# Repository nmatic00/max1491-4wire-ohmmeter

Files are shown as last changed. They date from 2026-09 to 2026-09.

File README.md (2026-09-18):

# Low-Resistance Meter (2–200 Ω)

This is my first project.

Portable digital ohmmeter designed for accurate low-resistance measurements. This project covers the full electronic system design, including schematic, pcb, enclosure and documentation.

Developed as a coursework project for **Design of Industrial Devices and Measurement Systems 1**.
---

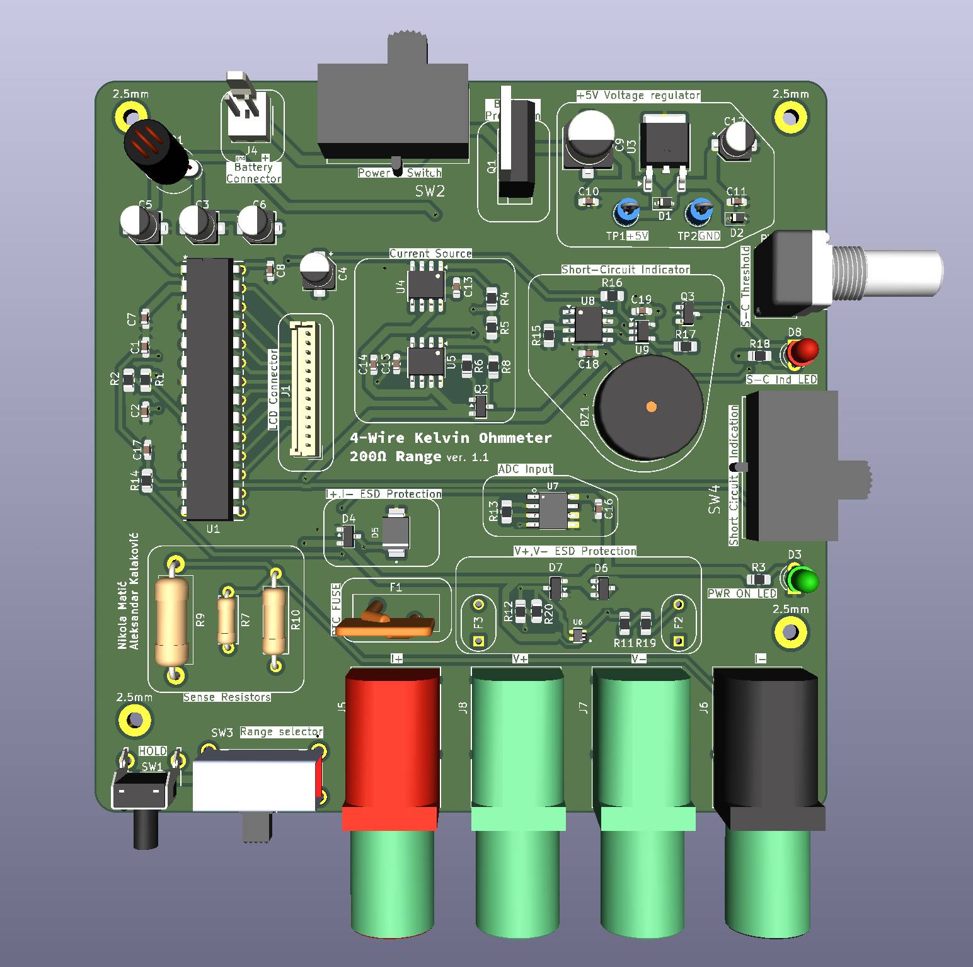
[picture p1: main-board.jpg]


---

## Technical Specifications

| Parameter | Specification |
| :--- | :--- |
| **Measurement Range** | 2 Ω, 20 Ω, and 200 Ω full-scale |
| **Current Source** | 1 mA, 10 mA, and 100 mA (switch-selectable) |
| **Display** | $3\frac{1}{2}$-digit multiplexed LCD (VIM-503-DP-RC-S-HV via MAX1491) |
| **Power Supply** | Single 9 V battery (BT1) with internal +5 V regulation (LM78M05) |
| **Measurement Method** | 4-wire (Kelvin) sensing |
| **Form Factor** | 2-layer $100 \times 100\text{ mm}$ SMD PCB |

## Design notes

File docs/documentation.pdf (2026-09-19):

## PROJECT DOCUMENTATION

# DIGITAL OHMMETER WITH 200 Ω MAXIMUM RANGE

Students: Nikola Matić (EM13/2019), Aleksandar Kalaković (EM23/2019)

Mentor: dr.Marjan Urekar

Design of Industrial Devices and Measurement Systems 1

17.5.2026

1

## Table of Contents

2

## 1 Motivation

The assignment for the course "Design of Industrial Devices and Measurement Systems 1" is to develop a project that demonstrates knowledge and skills in designing the schematic and printed circuit board (PCB) for an electrical device. The project focuses on the development of an instrument for measuring resistance up to 200 Ω. The goal of the project is to acquire and expand knowledge in the field of electronics and low-resistance measurement.

## 2 Introduction

The goal of this project is the development of a measuring instrument capable of measuring resistance in the range of 2 to 200 Ω with practical application in an industrial environment or laboratory.This documentation comprehensively covers the instrument's design, operational principles, and the selection of components integrated into the device itself. The approaches to challenges encountered during development will also be explained sequentially according to the stages of development.

IC | Consumption
MAX1491 | 980 µA
VIM 503-DP-RC-S-HV | 10 µA
LM78M05_TO252 | 10 mA
3x OPA197IDGKT | 3x 1 mA
INA826 | 200 µA
MAX9031AU | 55 µA
Power LED | 15 mA
Ind. k.s. LED | 15 mA
AI-1223-TWT-5V-5-R | 30 mA
Total: | 72.245 mA

Table 1: Consumption estimation Note: The specified values apply to T = 25°C.

3

## 3 Schematic

### 3.1 Power supply

The device is designed to be powered by a single 9 V battery (BT1) that supplies the device with +9 V. The battery is located on a separate board with dedicated access on the enclosure for easier replacement. The battery board connects to the main board of the device via a two-pin power connector (J3 and J4).

On the main board, after the connector, there is a power switch. The switch (SW2) is an SPST (single pole single throw) type, which meets the device's requirements given that it uses a unipolar power supply. The switch allows the user to turn the device on or off without the need to physically disconnect the battery.

The device features reverse polarity protection using a PMOS transistor (Q1) to protect the device in the event of an incorrectly connected battery, connector, etc. Under reverse battery polarity, the PMOS will not conduct, thereby preventing potential damage to the other components of the device. We use the PMOS FQP27P06 because it has a low Rds(on), thereby creating a negligible voltage drop—much lower than if we had used a diode. The Vgs is also critical for us, which for this transistor is ±25 V, enabling reliable protection against a reverse-polarized 9 V battery.

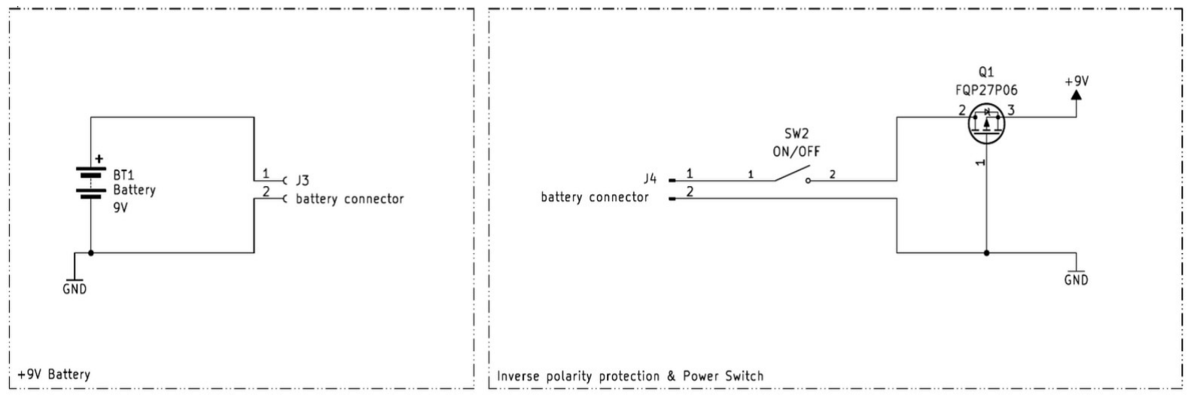
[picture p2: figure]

Figure 1: Battery & Inverse polarity protection

4

Further, the +9 V voltage is fed to the +5 V regulator (U3). This +5 V voltage is used to power all circuits in the device. For the +5 V regulator, we use the LM78M05. This regulator is key to providing a stable voltage for all device components. The regulator was chosen according to the power supply needs (+5 V) and the total current the device can draw. The LM78M05 can provide up to 500 mA of current, which satisfies the needs of this device and leaves headroom for safety. Diodes (D1 and D2) serve to protect the regulator itself from reverse current flow.

Capacitors (C9, C10, C11, C12) serve to further stabilize the voltage and reduce the impact of environmental noise. Two electrolytic capacitors (C9, C12) and two ceramic block capacitors (C10, C11) are used.
At the output of the regulator, there is an indicator LED (D3) that serves to indicate the state of the device. Test points (TP1 and TP2) allow easy access to the supply voltage for easier diagnostics.

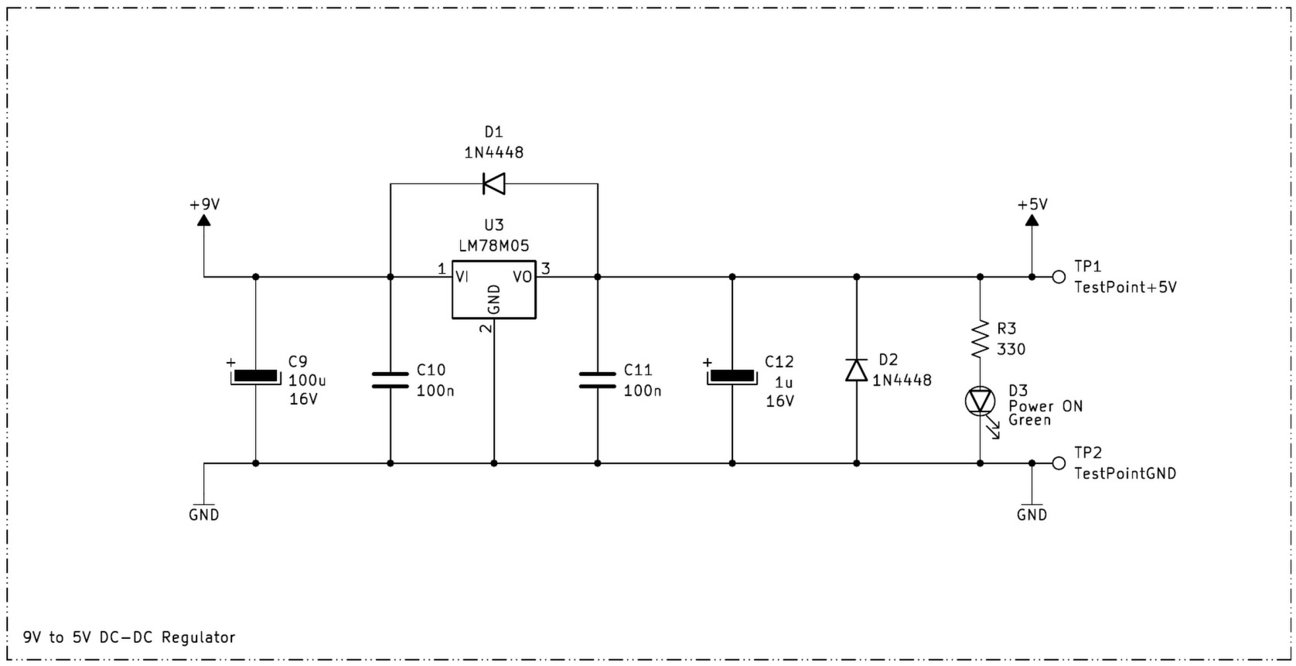
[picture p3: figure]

Figure 2: 9 V to 5 V DC-DC regulator

5

### 3.2 Current source

To design the ohmmeter, a constant current source is required. In order to determine the value of the resistance being measured, we must pass a known current through that resistance and then measure the voltage drop across it. The constant current source consists of two operational amplifiers (U4 and U5), a PMOS transistor (Q2), and sense resistors (R7, R9, R10). This current source is designed to precisely provide the current value required for a given measurement. It is adjustable across ranges of 1 mA, 10 mA, and 100 mA, which correspond to the measurement ranges of this device (200 Ω, 20 Ω, and 2 Ω, respectively). Range selection is implemented using a DP3T switch (SW3), which selects the current range while simultaneously sending a signal to the main chip regarding the selected range—i.e., the position of the decimal point.

The current source features overvoltage protection and electrostatic discharge (ESD) protection, as well as a PTC fuse that protects against overcurrent. Overvoltage protection is realized using a pair of BAT54S diodes (D4) that clamp the voltage within the operating voltage range. ESD protection is implemented via an SMBJ5.0A TVS diode (D5), which protects the remaining components in the event of a surge. In the case of a fault current, a resettable PTC fuse (F1) with a hold current of up to 200 mA trips to isolate the circuit. The output of this current source is provided via S16N-PC jacks (J5 and J6), which serve as the device's current terminals.

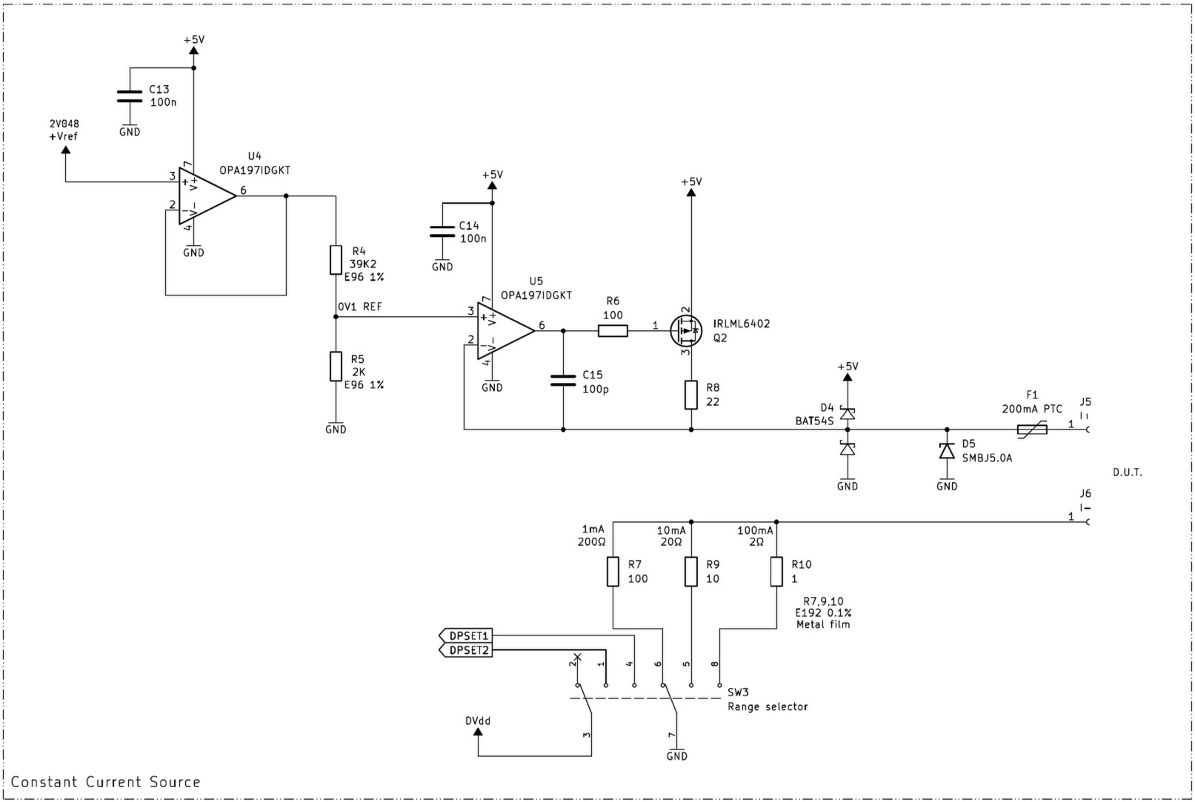
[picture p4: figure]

Figure 3: Constant Current Source

6

### 3.3 Input element

The input stage of the device consists of two S16N-PC jacks, input protection, an INA826 instrumentation amplifier, and an RC filter. The jacks (J7 and J8) serve as the voltage sense terminals of the device and are connected to the ADC inputs via the INA826 instrumentation amplifier (U7).

Input protection is implemented through a pair of PTC fuses (F2 and F3), a two-channel bidirectional TVS diode TP2E001DRLRG4 (U6) that protects the inputs from ESD, and two pairs of BAT54S diodes (D6 and D7) that provide overvoltage protection. The inputs of the instrumentation amplifier (U7) are protected against overcurrent by resistors (R11, R19 and R12, R20) in a manner that does not significantly affect measurement accuracy due to the low input bias current of the INA826 (U7). The instrumentation amplifier (U7) is configured to amplify the voltage signal with a range up to 200 mV to 2 V, for which the ADC is calibrated.

The RC filter formed by the combination of a resistor (R14) and a capacitor (C17) serves to eliminate external noise that could affect the measured signal. This is achieved by attenuating high frequencies typical of external interference.

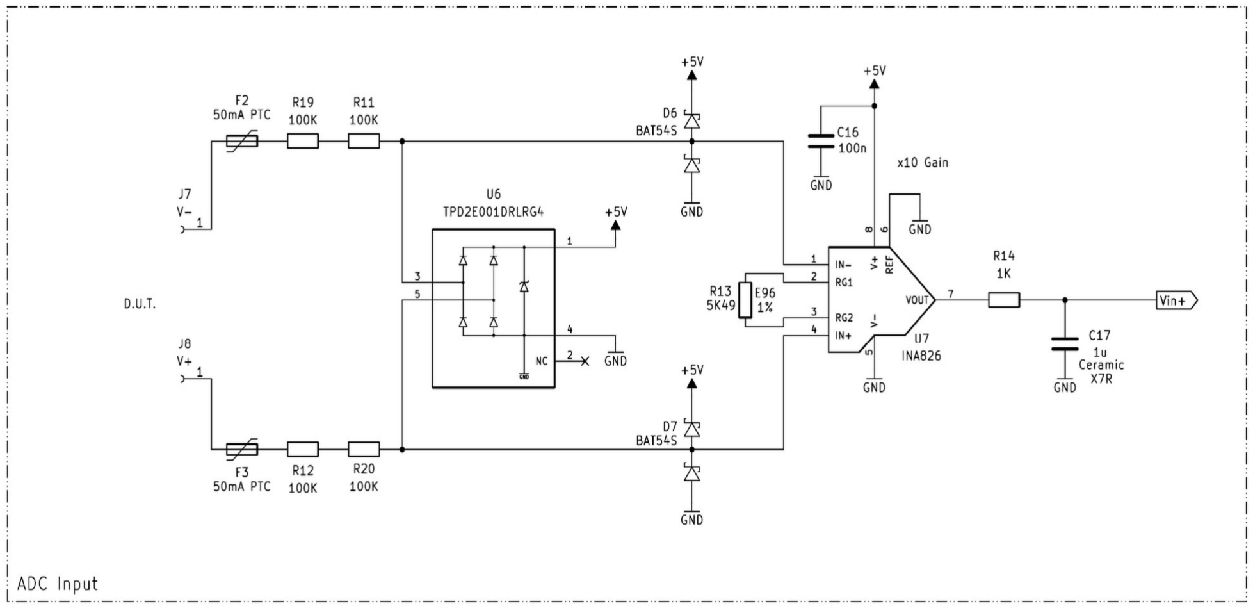
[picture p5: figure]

Figure 4: Input element

7

### 3.4 Continuity tester

The continuity tester is useful when diagnosing circuits. The indicator threshold is adjustable from 1 to 50 Ω and features both audio and visual indication.

A MAX9031 comparator (U9) is used to detect a "short circuit" using an adjustable reference voltage. This comparator features an integrated 4 mV hysteresis, which prevents output oscillation near the comparison threshold.

The reference voltage is implemented via a voltage divider consisting of a resistor (R16) and a potentiometer (RV1). The voltage divider is configured for a range corresponding to 1 to 50 Ω. By adjusting the potentiometer, the user can tune the comparator's voltage threshold.

Audio indication is provided by an active buzzer (BZ1) that emits a high-frequency tone upon detecting a "short circuit". Visual indication is provided by a red LED (D8).

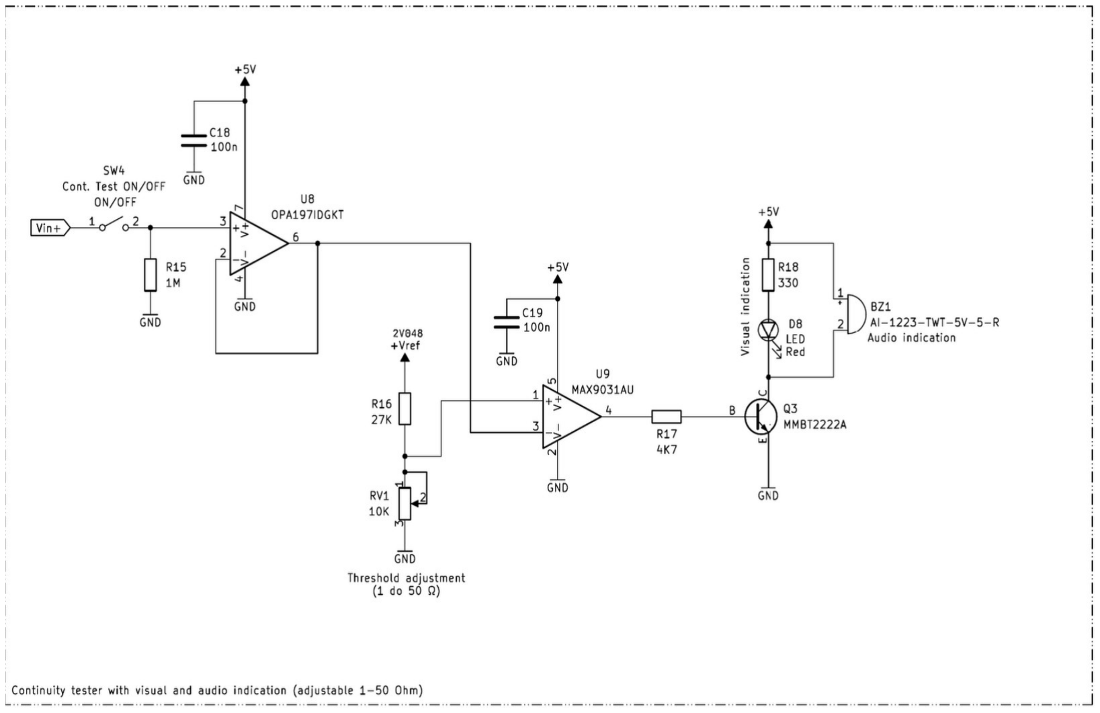
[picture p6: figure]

Figure 5: Continuity Tester

8

### 3.5 ADC circuit

A MAX1491 (U1) is used, which is an ADC with integrated LCD drivers offering 3½-digit resolution. This ADC provides high measurement precision and enables easy display of results on an LCD screen. Its low power consumption makes it suitable for battery-powered measuring devices. It is set to a 2 V range via the RANGE pin (pin 10) connected to ground, which corresponds to the output of the instrumentation amplifier.

A HOLD function is provided via a push button (SW1). This feature allows the user to freeze the displayed measurement result on the LCD screen at the press of a button. Low battery voltage indication is implemented using a voltage divider (R1, R2). When the battery voltage drops below 4.7 V, the LOWBATT segment lights up on the LCD screen.

The LCD outputs of the MAX1491 are multiplexed using triplex logic with a ⅓ duty cycle signal. This approach significantly reduces the number of pins required to interface with the LCD screen. The LCD outputs are connected to the LCD connector (J1).

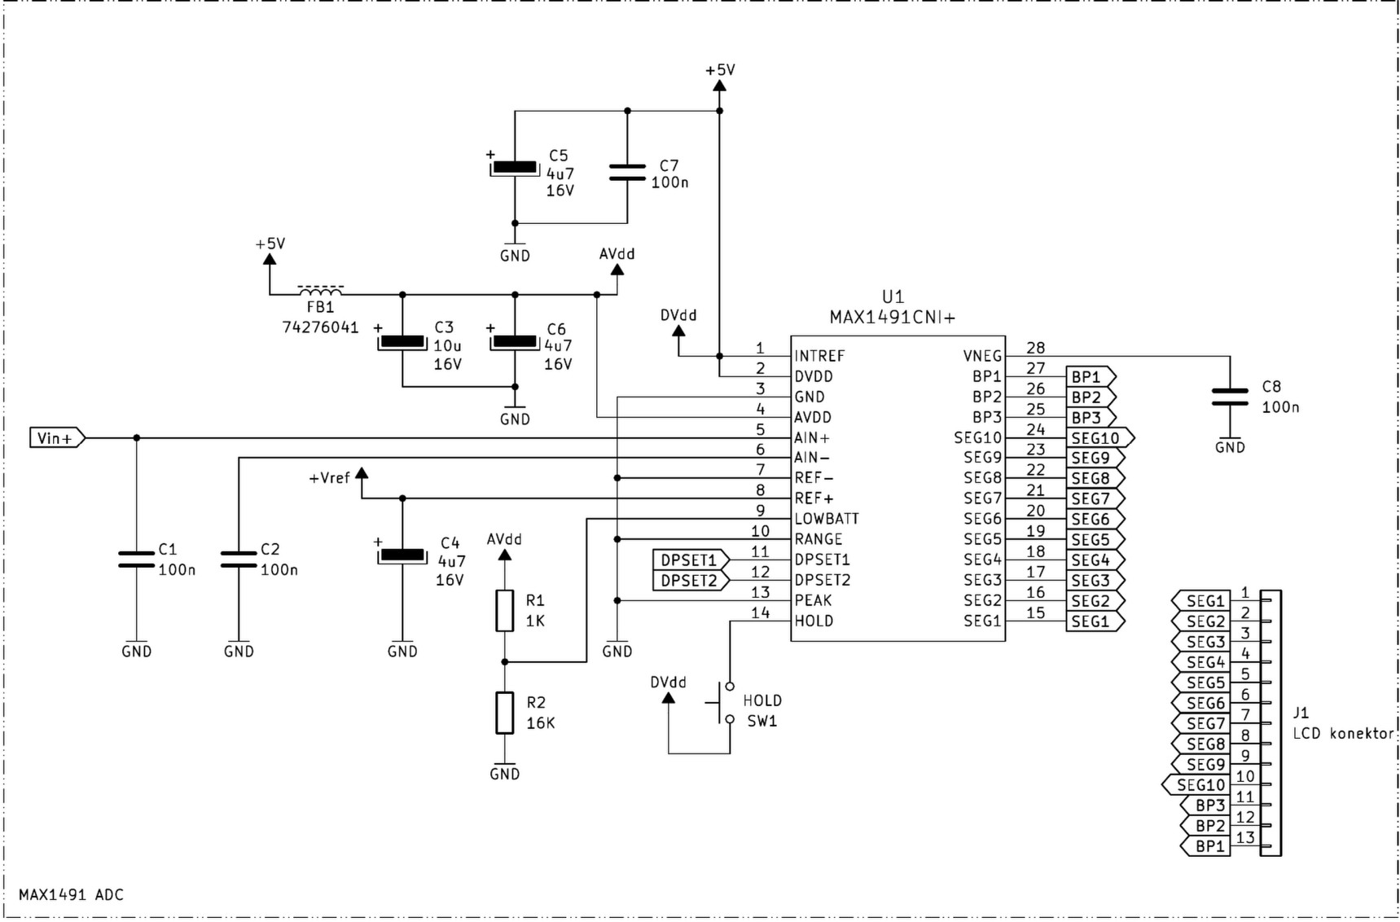
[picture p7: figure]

Figure 6: ADC circuit

9

### 3.6 LCD

The LCD screen (U2) is mounted on a separate PCB for greater flexibility when assembling it into the enclosure. The LCD connects to the MAX1491 via LCD connectors (J1 and J2). The connector used is a Hirose DF13-13P. The LCD used is the VIM-503-DP-RC-S-HV. It is a static TN panel with multiplexed inputs, enabling straightforward interfacing with the MAX1491. The LCD panel itself features a 4½-digit display, of which 3½ digits are used to match the output of the MAX1491. Selecting this LCD represents a trade-off regarding project complexity; while a 3½-digit LCD with the same triplex multiplexing scheme is theoretically possible, it was not off-the-shelf available and would require custom manufacturing. Choosing this display avoids the complexity of adapting a passive display panel to the MAX1491 output logic.

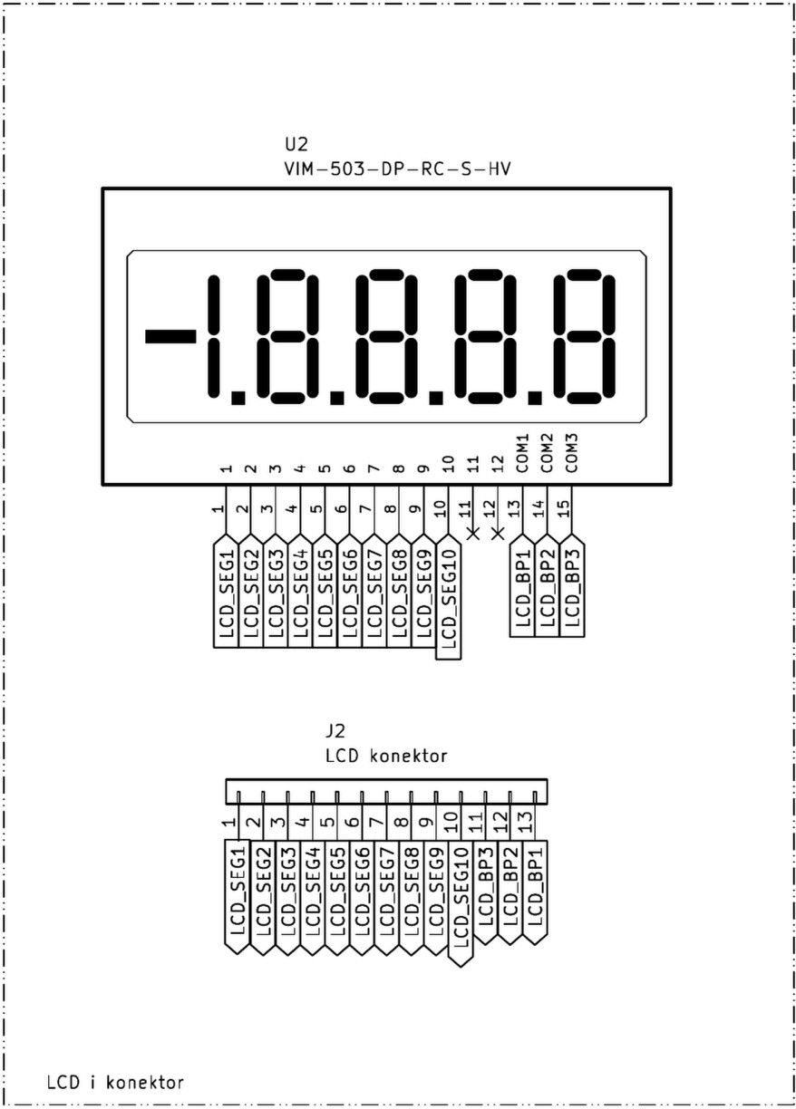
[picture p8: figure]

Figure 7: LCD & Connector

10

## 4 PCB

### 4.1 Main board

The board is constructed with two layers, with components placed on the top layer. Both layers feature a copper pour tied to ground (GND). This simplifies ground routing and minimizes the amount of copper that needs to be etched off during production. It also improves electromagnetic stability, making the device more resistant to noise.

Trace widths on the board were chosen to guarantee proper functionality and ensure physical durability:
- 50 mils (1.270 mm) for power supply traces
- 20 mils (0.508 mm) for signal traces

The aforementioned input protections are located away from other circuitry to prevent potential damage from high temperatures, overcurrent, or arcing. It is critical that these protective components be placed close to the input jacks for rapid fault response (especially PTC fuses F1, F2, and F3).

The voltage sense terminals are positioned between the current terminals with clear spacing to naturally discourage improper connections by the user. Color-coded terminals further reinforce this setup: the I+ terminal is red, while I- is black. The device is designed for use with specialized cables known as Kelvin clamps, which connect to I+ and V+, and I- and V-, respectively.

The device controls are strategically positioned along the edges of the board. The power switch is located on the rear panel, while the input jacks, HOLD button, and range selector are on the front panel. The short-circuit indicator switch and its threshold adjustment potentiometer are positioned on the right side.

All components on the board are grouped by circuit function and clearly labeled on the silkscreen. This significantly simplifies cross-referencing schematic functional blocks with physical board components. The PCB is designed primarily around SMD (Surface Mount Device) components. Compared to THT (Through Hole Technology), SMD components allow for a significantly smaller form factor, enabling the main board to fit within a 100x100 mm footprint. Compact physical dimensions are vital here, as a battery-powered device must remain portable and easy to handle.

11

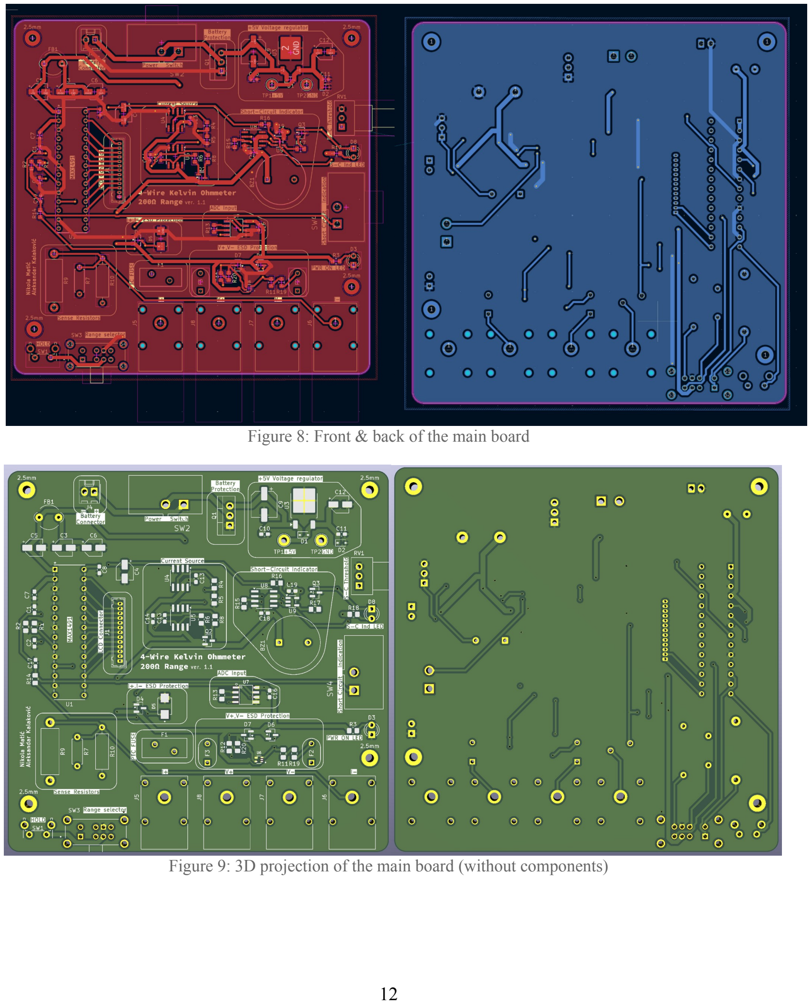
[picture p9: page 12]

Figure 8: Front & back of the main board

Figure 9: 3D projection of the main board (without components)

12

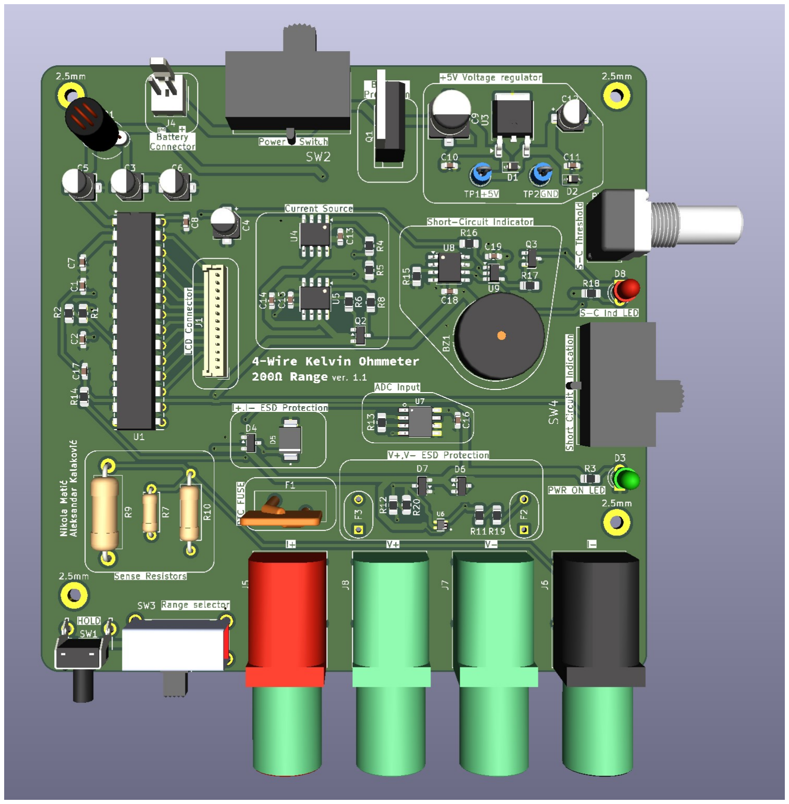
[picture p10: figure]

Figure 10: Main board with components

13

### 4.2 LCD board

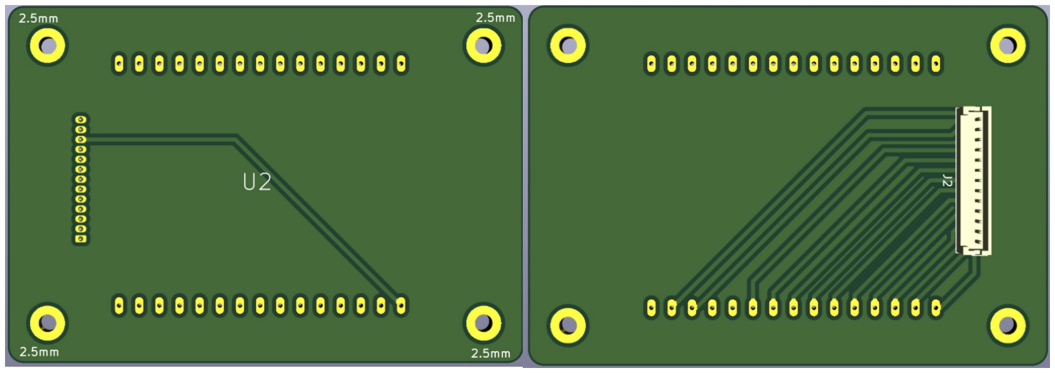
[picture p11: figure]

Figure 11: Front & back of the LCD board

### 4.3 Battery board

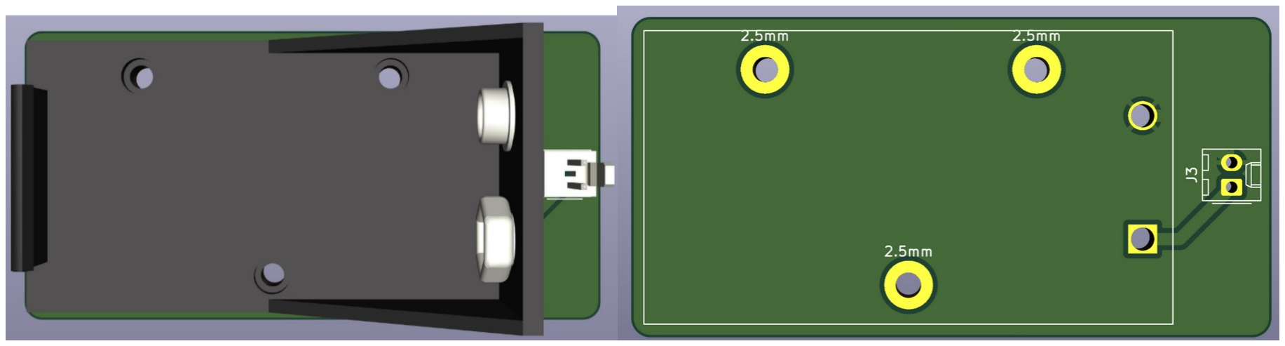
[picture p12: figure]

Figure 12: Front & back of the battery board

14

## 5 Enclosure

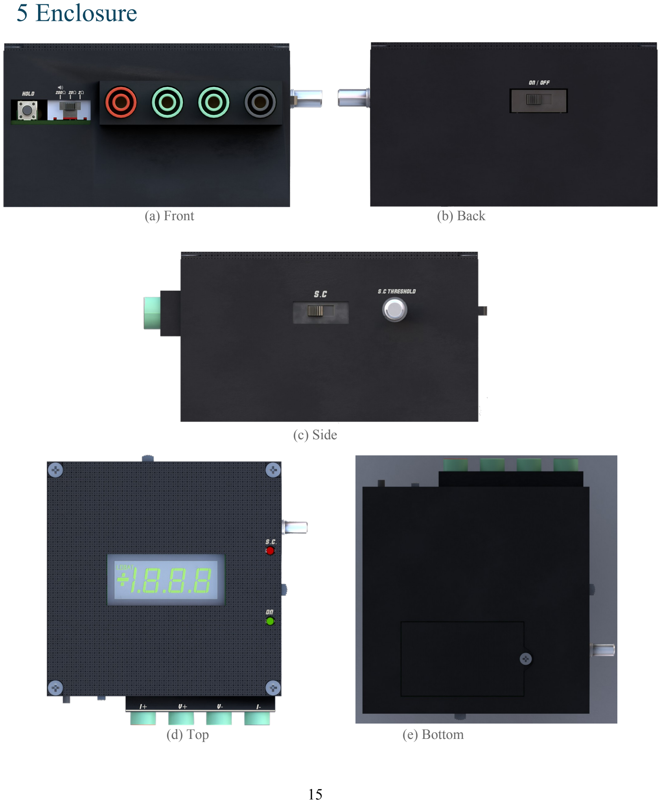
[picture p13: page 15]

(a) Front | (b) Back
(c) Side
(d) Top | (e) Bottom

15

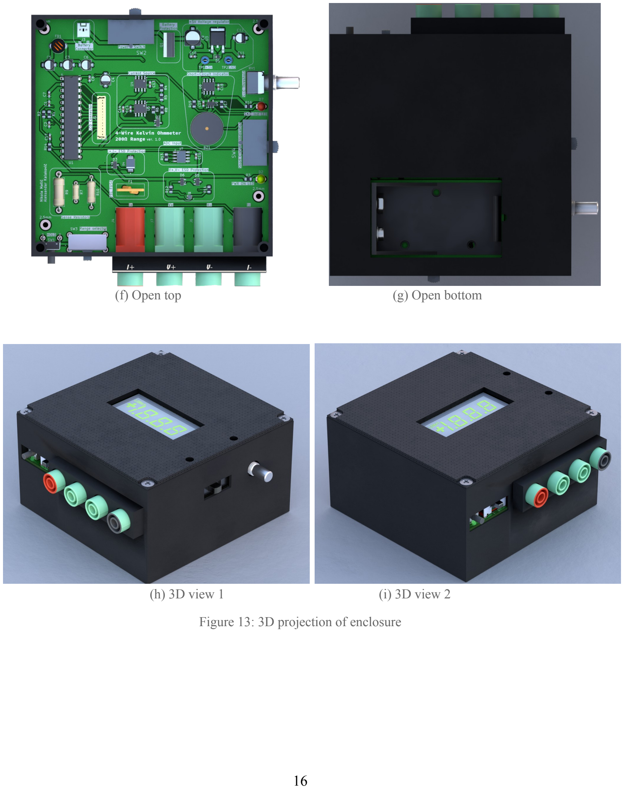
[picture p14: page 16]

(f) Open top | (g) Open bottom
(h) 3D view 1 | (i) 3D view 2

Figure 13: 3D projection of enclosure

16

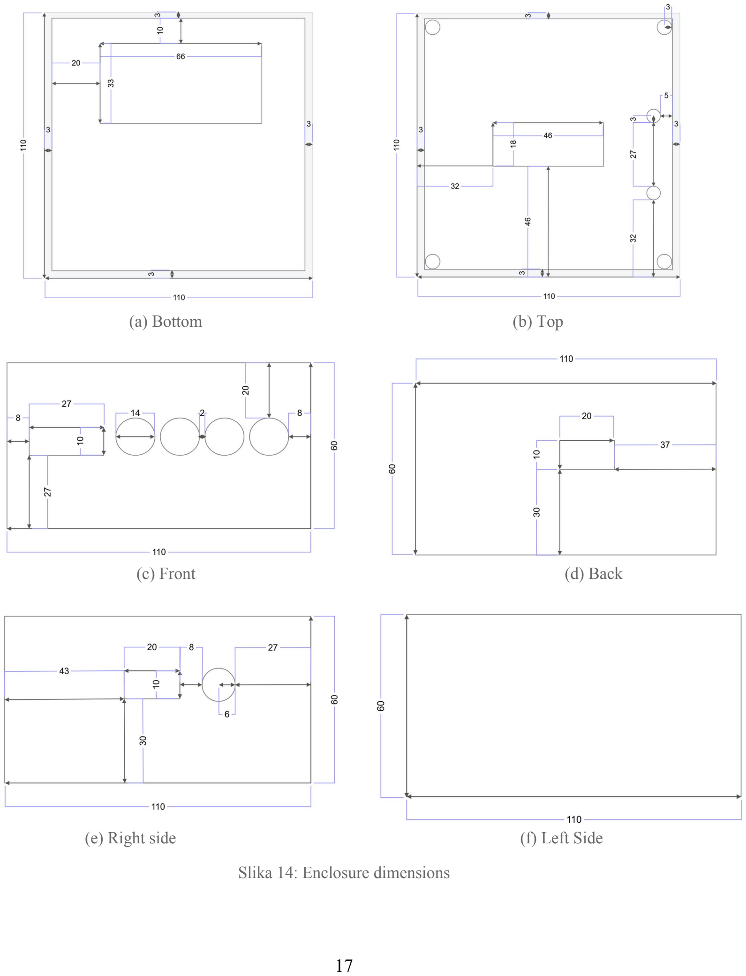
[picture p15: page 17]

(a) Bottom | (b) Top
(c) Front | (d) Back
(e) Right side | (f) Left Side

Slika 14: Enclosure dimensions

17

## 6 BOM

Item | Value | Reference | Footprint | Qty Mfr. part No. | Price (piece)(€)Price (€)
1 | Battery | BT1 | 12BH611-GR | 1 | 12BH611-GR | 1,46 | 1,46
2 | Buzzer | BZ1 | AI-1223-TWT-5V-5-R | 1 | AI-1223-TWT-5V-5-R | 1,35 | 1,35

3 100n

C1, C2, C7, C8,
C10, C11, C13,
C14, C16, C18,
C19 | _0603 | 11 GCM188R71H104KA57D | 0,03 | 0,33
4 | 10u | C3 | 4x5.4 | 1 | EXV106M035A9DAA | 0,43 | 0,43
5 | 4u7 | C4, C5, C6 | 4x5.4 | 3 | EXV475M035A9BAA | 0,37 | 1,11
6 | 100u | C9 | 6.3x5.9 | 1 | MAL214699805E3 | 1,79 | 1,79
7 | 1u | C12 | 4x4.5 | 1 | EDH105M050A9BAA | 0,16 | 0,16
8 | 1u | C17 | _0603 | 1 | 0603X7R105KT7AT | 0,49 | 0,49
9 | 100p | C15 | _0603 | 1 | KGQ15ACG2A101JM | 0,05 | 0,05
10 | 1N4448 | D1 | SOD-323 | 1 | 1N4448WS-HE3_A-08 | 0,55 | 0,55
11 | Power ON | D2 | LED_D3.0mm | 1 | SLX-LX3054HD | 0,04 | 0,04
12 | BAT54S | D3, D5, D6 | SOT-23 | 3 | BAT54S | 0,12 | 0,36
13 | SMBJ5.0A | D4 | DIOM4336X265N | 1 | SMBJ5.0A | 0,53 | 0,53
14 | LED | D7 | LED_D3.0mm | 1 | SLX-LX3054HD | 0,04 | 0,04
15 | PTC Fuse | F1 | MF-RX020/72-0 | 1 | MF-RX020/72-0 | 0,34 | 0,34
16 | Ferrite Bead | FB1 | 28C0236-0JW-10 | 1 | 74276041 | 0,12 | 0,12
17 | LCD konektor | J1, J2 | Hirose_DF13-13P-1.25DSA 2 | DF13-13P-1.25DSA(55) | 1,01 | 2,02
18 | Konektor baterije | J3, J4 | KK-254_AE-6410-02A | 2 | 22272021 | 0,18 | 0,36
19 | I+,I-,V+,V- | J5, J6, J7, J8 | FCR7350R_S16N-PC | 4 | FCR7350R_S16N-PC | 4,9 | 19,6
20 | FQP27P06 | Q1 | TO-220-3 | 1 | FQP27P06 | 2,51 | 2,51
21 | IRLML6402 | Q2 | SOT-23 | 1 | IRLML6402TRPBF | 0,39 | 0,39
22 | MMBT2222A | Q3 | SOT-23 | 1 | MMBT2222A | 0,1 | 0,1
23 | 1K | R1, R14 | _0805 | 2 | RMCF0805JG1K00 | 0 | 0
24 | 16K | R2 | _0805 | 1 | RC0805JR-0716KL | 0,09 | 0,09
25 | 330 | R3, R17 | _0805 | 2 | RK73B2ATTE331J | 0,1 | 0,2
26 | 39K2 | R4 | _0805 | 1 | CRCW201039K2FKEF | 0,3 | 0,3
27 | 2K | R5 | _0805 | 1 | RC0805FR-7W2KL | 0,1 | 0,1

18

28 | 100 | R7 | DIN0207 | 1 | PTF56100R00BYEB | 5,15 | 5,15
29 | 100 | R6 | _0805 | 1 | RK73B2ATTE101J | 0,1 | 0,1
30 | 22 | R8 | _0805 | 1 | SR0805JR-7W22RL | 0,1 | 0,1
31 | 10 | R9 | DIN0414 | 1 | UPF50B10RV | 4,5 | 4,5
32 | 1 | R10 | DIN0309 | 1 | RS1/21R000BB12 | 19,44 | 19,44

33 100K

| | R11, R12,
| | R19,R20 | _0805 | 4 | SG73S2ATTD104G | 0,2 | 0,8
34 | 5K49 | R13 | _0805 | 1 | RT1206FRE075K49L | 0,1 | 0,1
35 | 1M | R15 | _0805 | 1 | TC0550F1004T5G | 0,01 | 0,01
36 | 27K | R16 | _0805 | 1 | AC0805JR-0727KL | 0,09 | 0,09
37 | 4K7 | R18 | _0805 | 1 | CRCW08054K70JNEAIF | 0,29 | 0,29
38 | 10K | RV1 | RK09Y11 | 1 | RK09Y11L0001 | 1,84 | 1,84
39 | HOLD | SW1 | PTS645VM83-2 LFS | 1 | PTS645VM83-2 LFS | 0,34 | 0,34
40 | ON/OFF, Indikacija K.S. | SW2, SW4 | L101011ML04Q | 2 | L101011ML04Q | 2,55 | 5,1
41 | Odabir opsega | SW3 | MHS233RA04 | 1 | MHS233RA04 | 2,62 | 2,62
42 | MAX1491CNI+ | U1 | 21-0043D_28_MXM | 1 | MAX1491CNI+ | 15,24 | 15,24
43 | LM78M05_TO252 | U3 | TO-252-2 | 1 | LM78M05CDTX/NOPB | 1,39 | 1,39
44 | OPA197IDGKT | U4, U5, U8 | SOIC-8 | 3 | OPA197IDGKT | 1,78 | 5,34
45 | TPD2E001DRLRG4 | U6 | SOTFL50P160X60-5N | 1 | TPD2E001DRLRG4 | 0,77 | 0,77
46 | INA826 | U7 | SO-8 | 1 | INA826AID | 3,52 | 3,52
47 | MAX9031AU | U9 | SOT-23-5 | 1 | MAX9031AUK+T | 1,39 | 1,39
48 | VIM-503-DP-RC-S-HV | U2 | VIM-503-DP-RC-S-HV | 1 | VIM-503-DP-RC-S-HV | 5,66 | 5,66
49 | 50mA PTC | F2, F3 | CMF_RL50A-0_BRN | 2 | CMF-RL50A-0 | 0,61 | 1,22
Total: | | | | | | | 109,8

Table 2: BOM (Mouser 20.5.2026.)

19

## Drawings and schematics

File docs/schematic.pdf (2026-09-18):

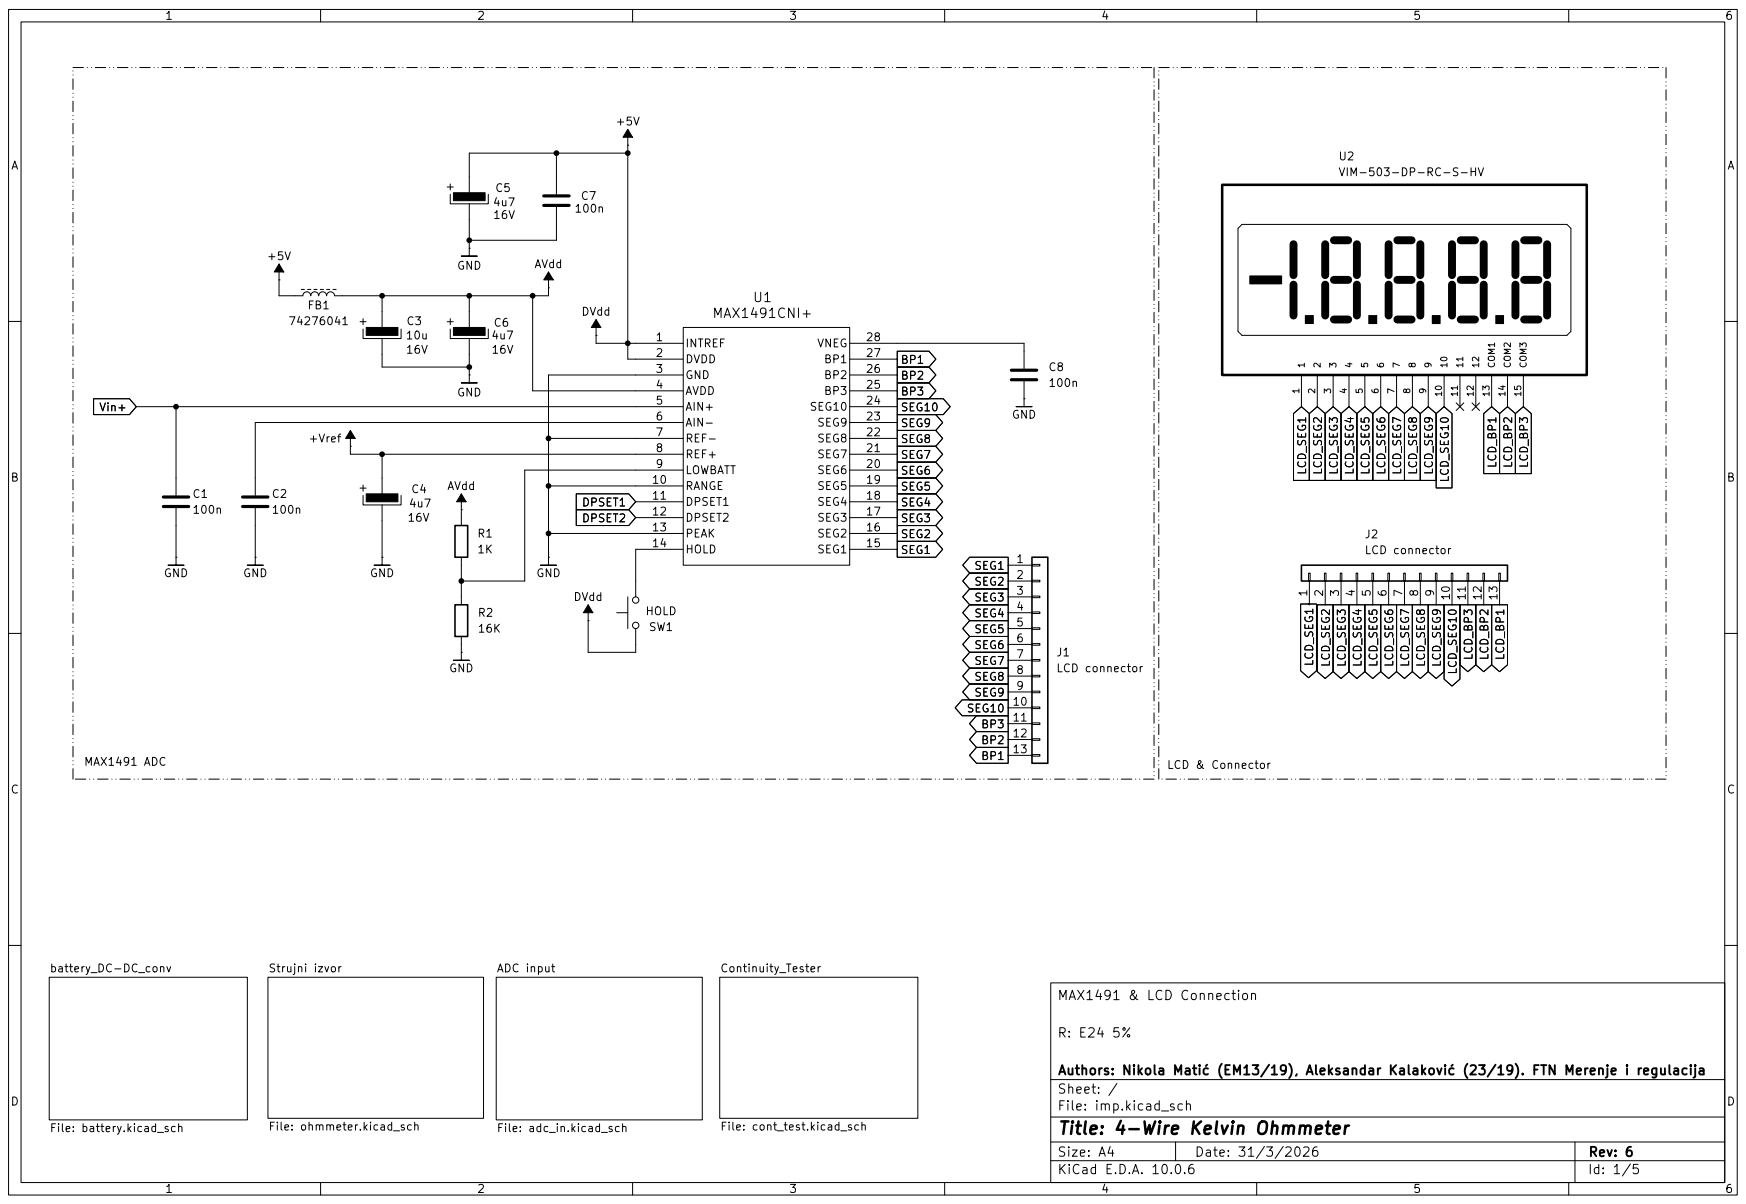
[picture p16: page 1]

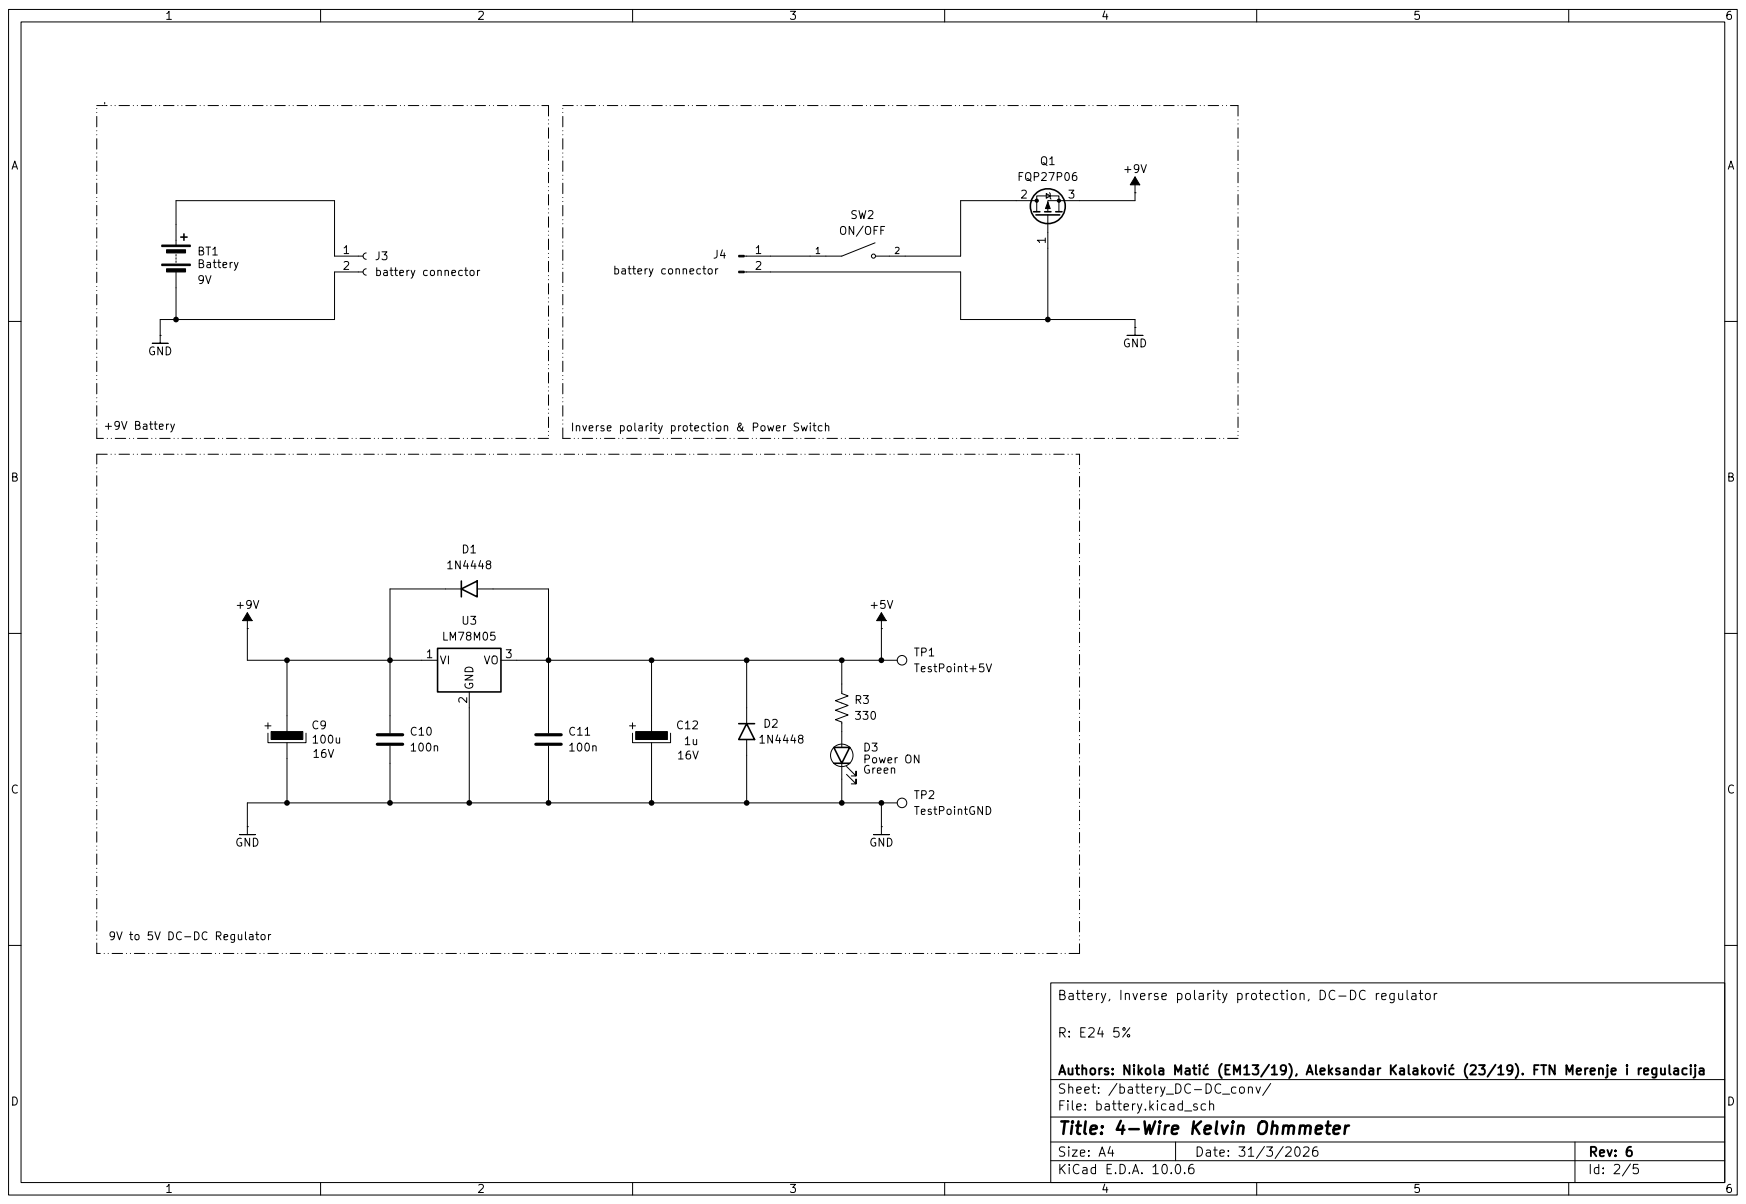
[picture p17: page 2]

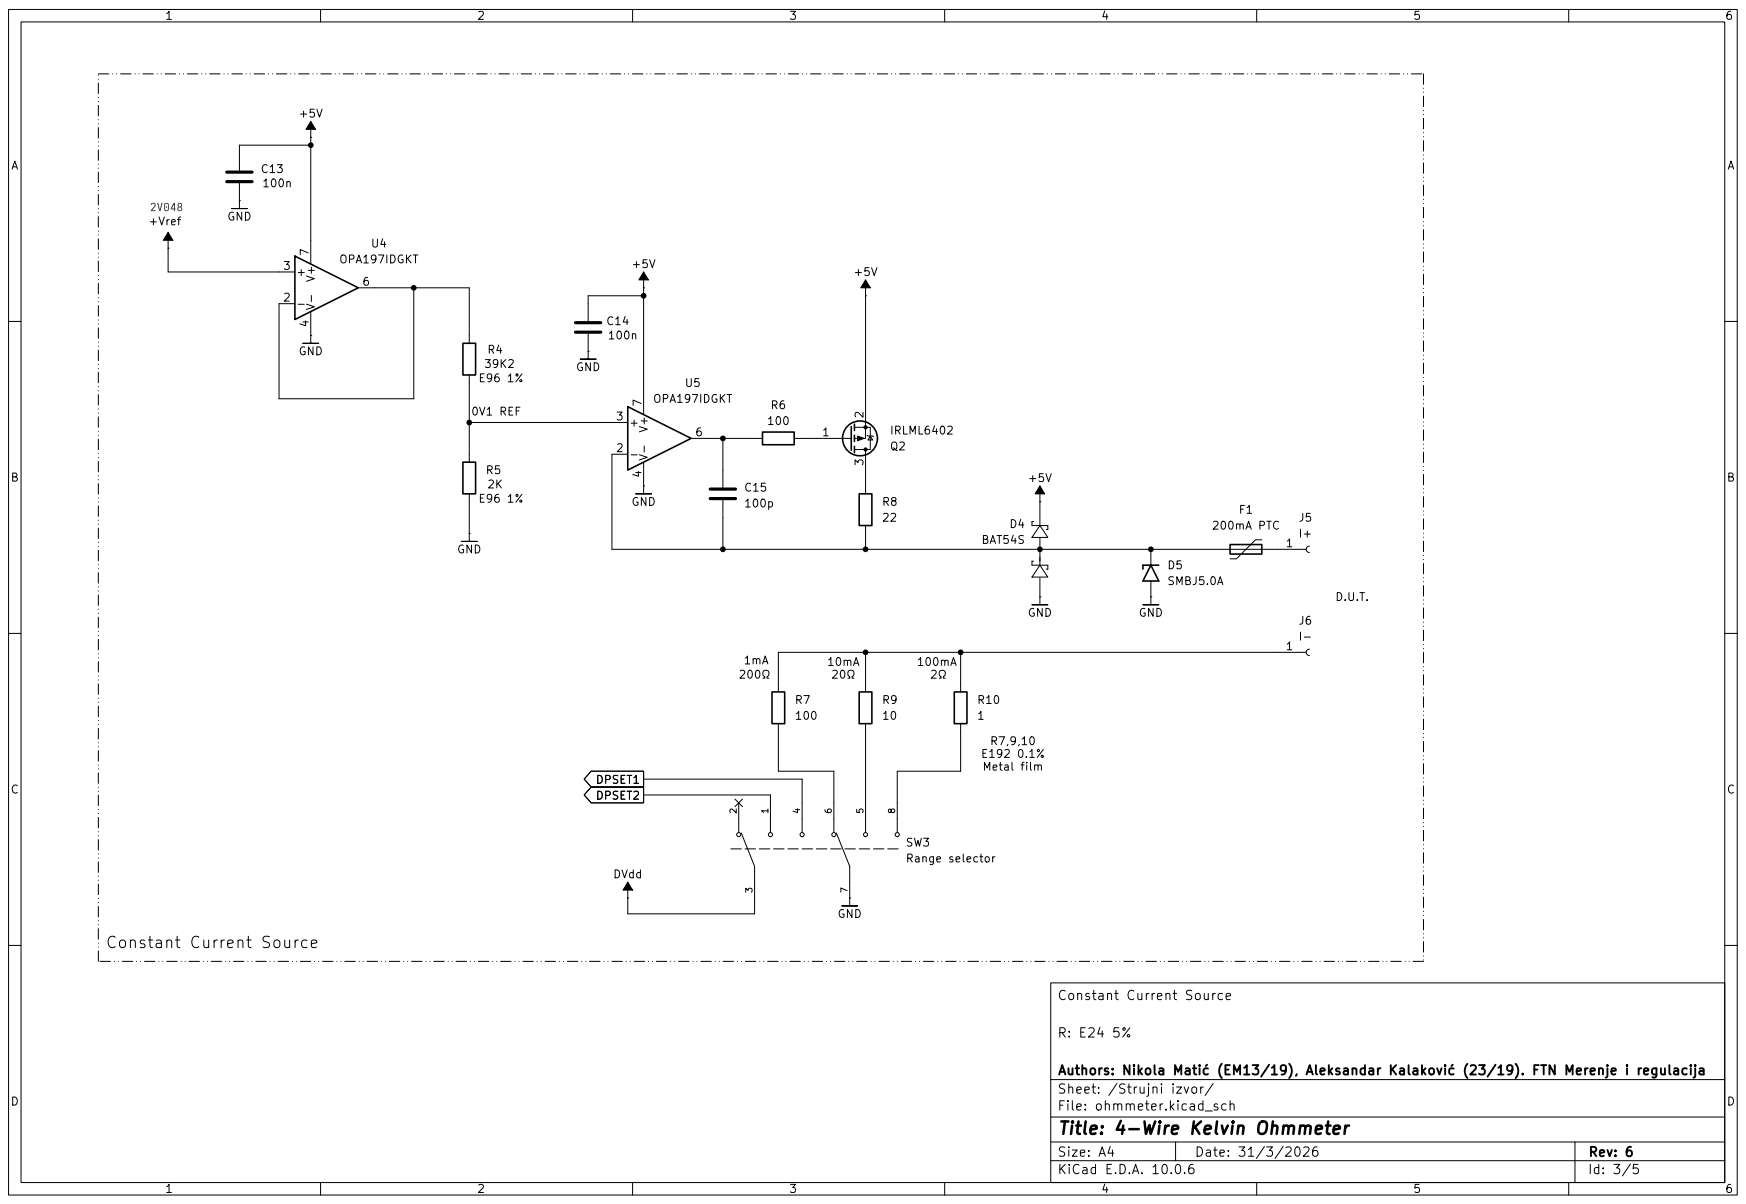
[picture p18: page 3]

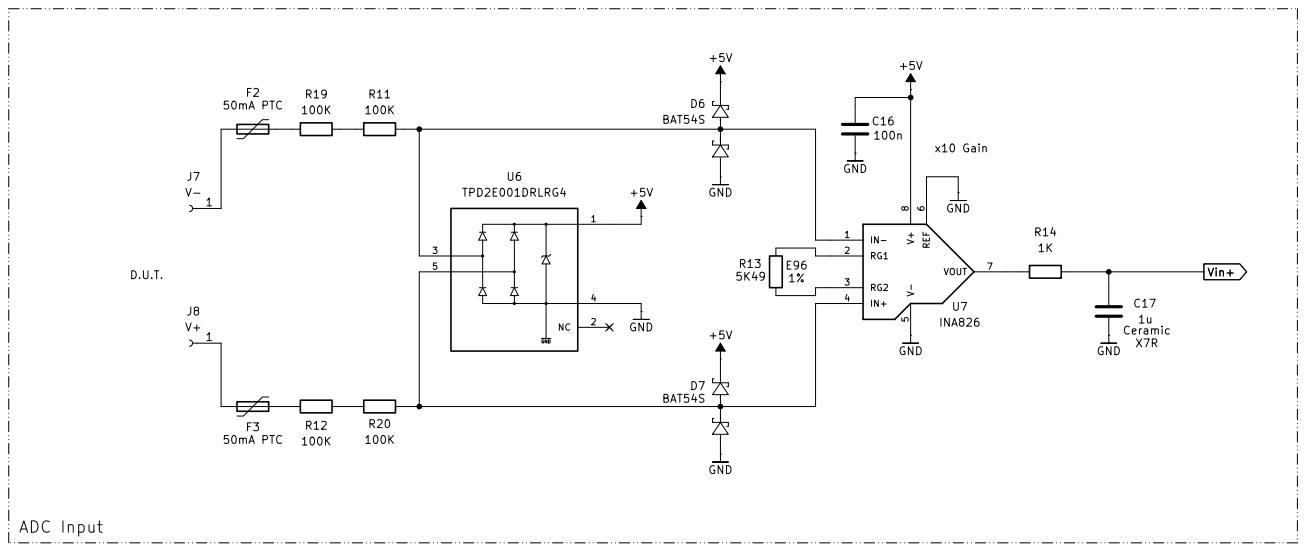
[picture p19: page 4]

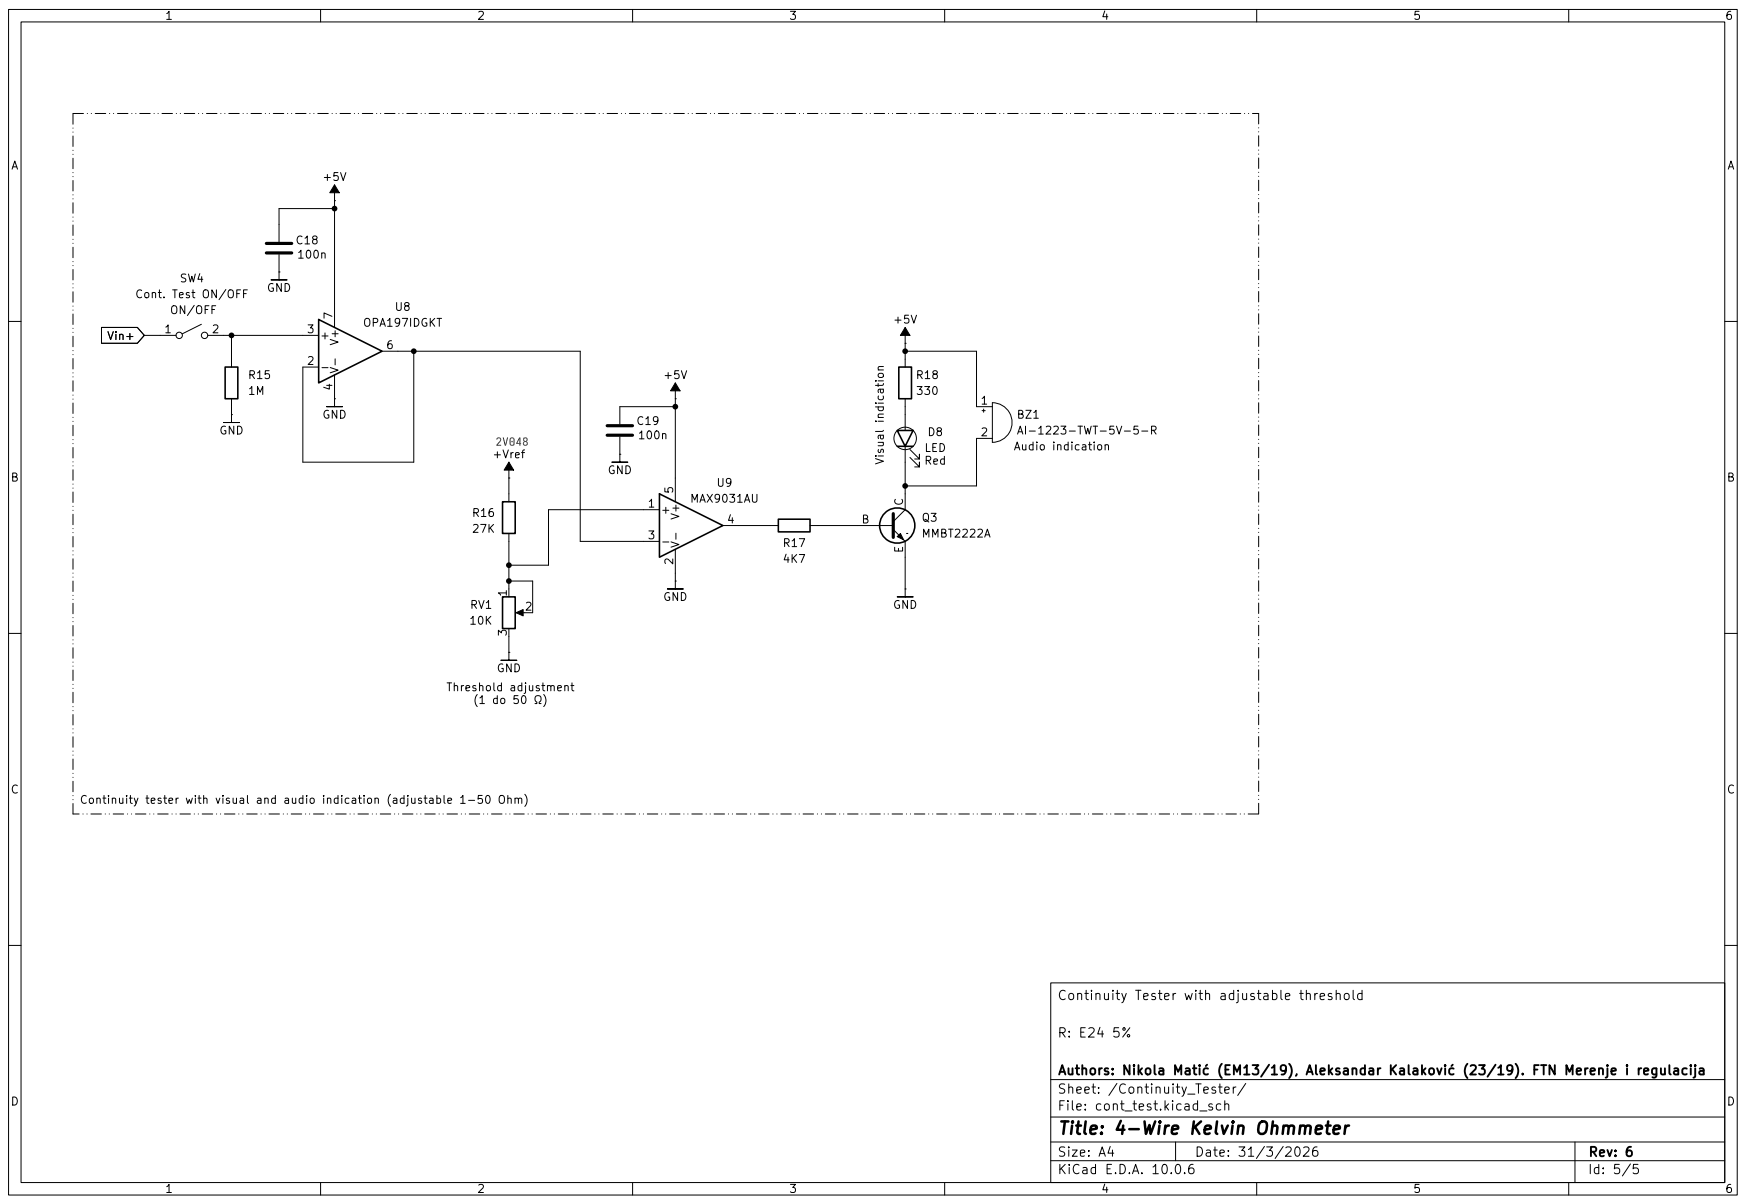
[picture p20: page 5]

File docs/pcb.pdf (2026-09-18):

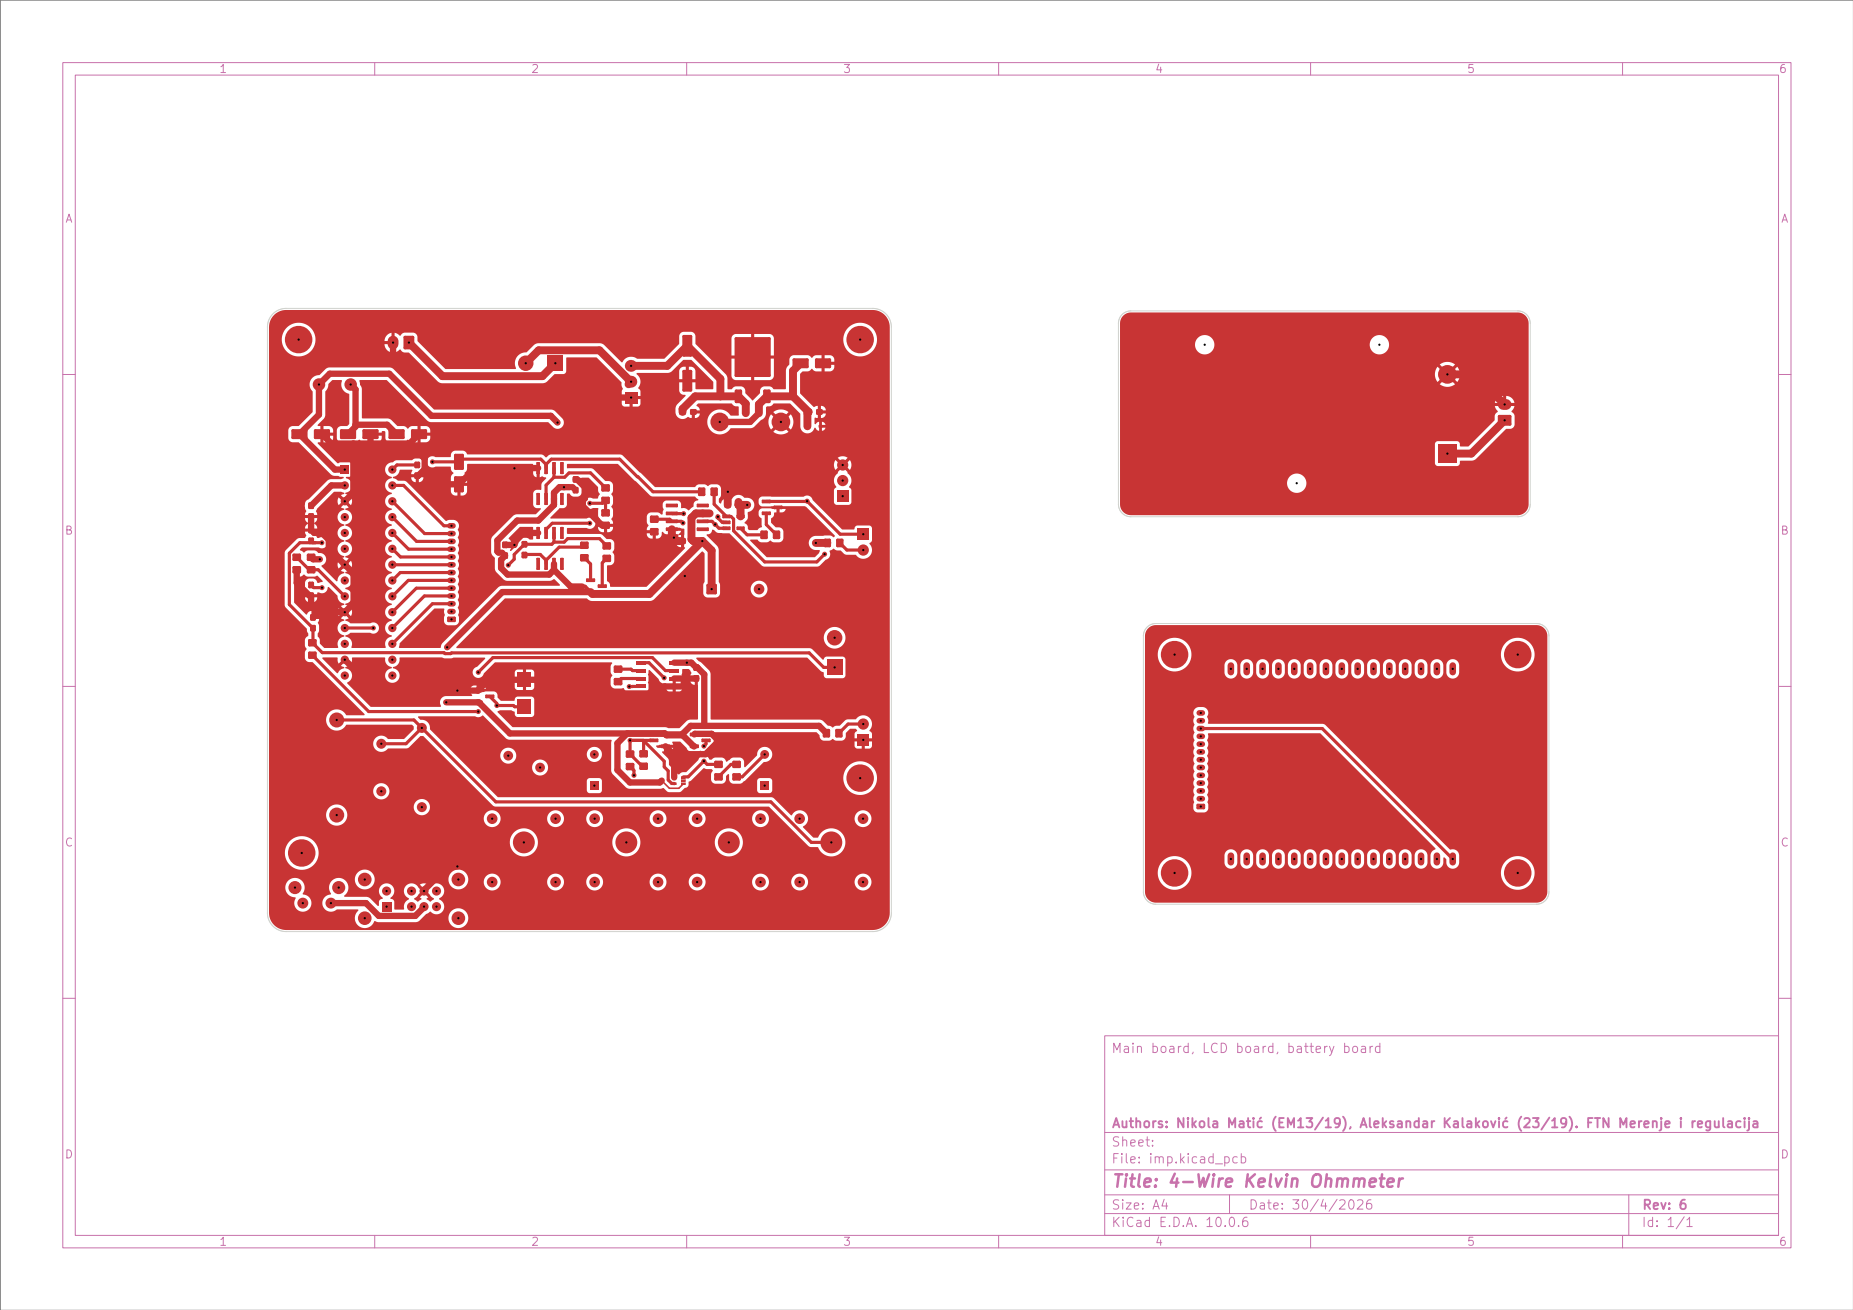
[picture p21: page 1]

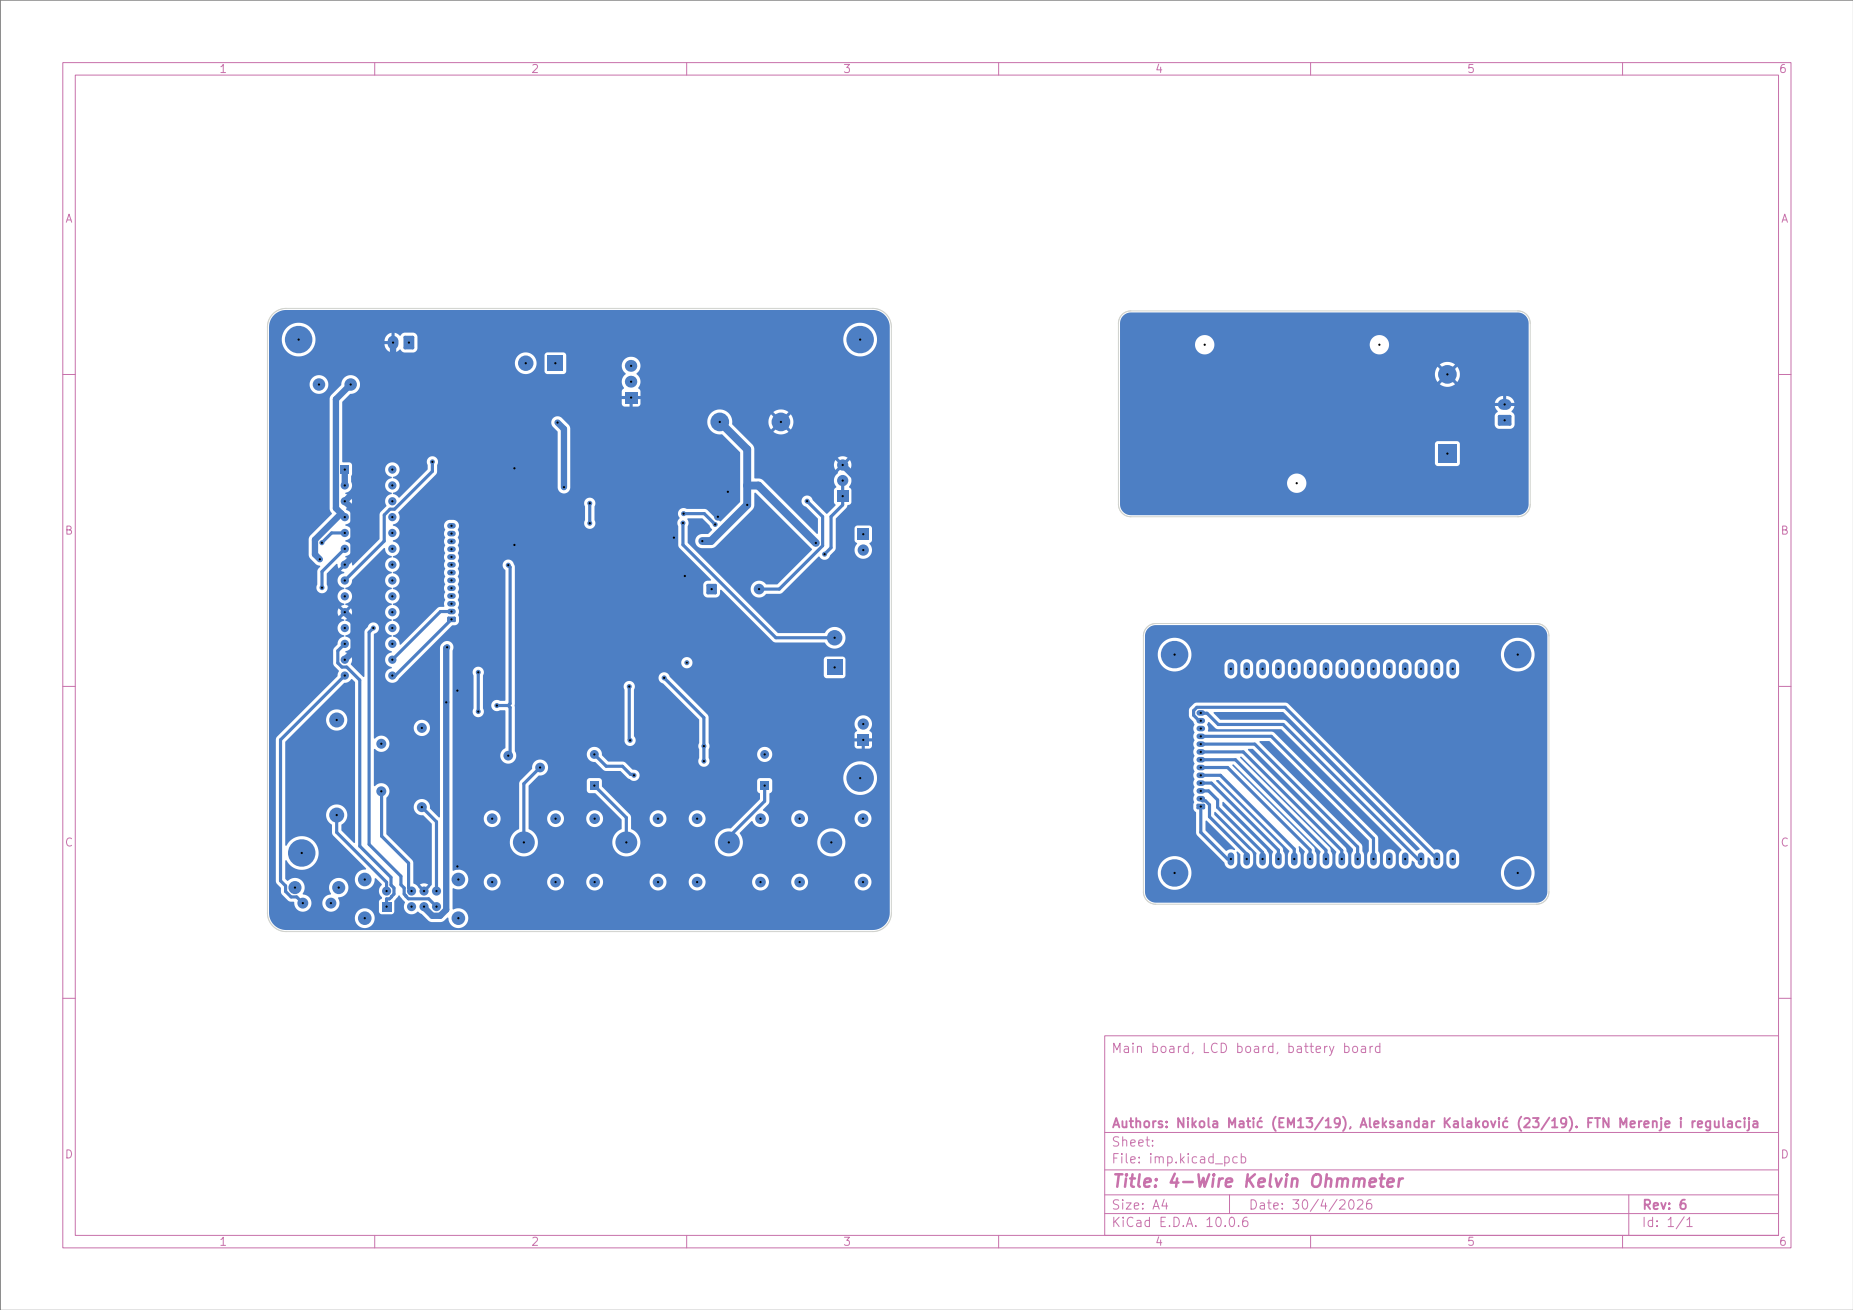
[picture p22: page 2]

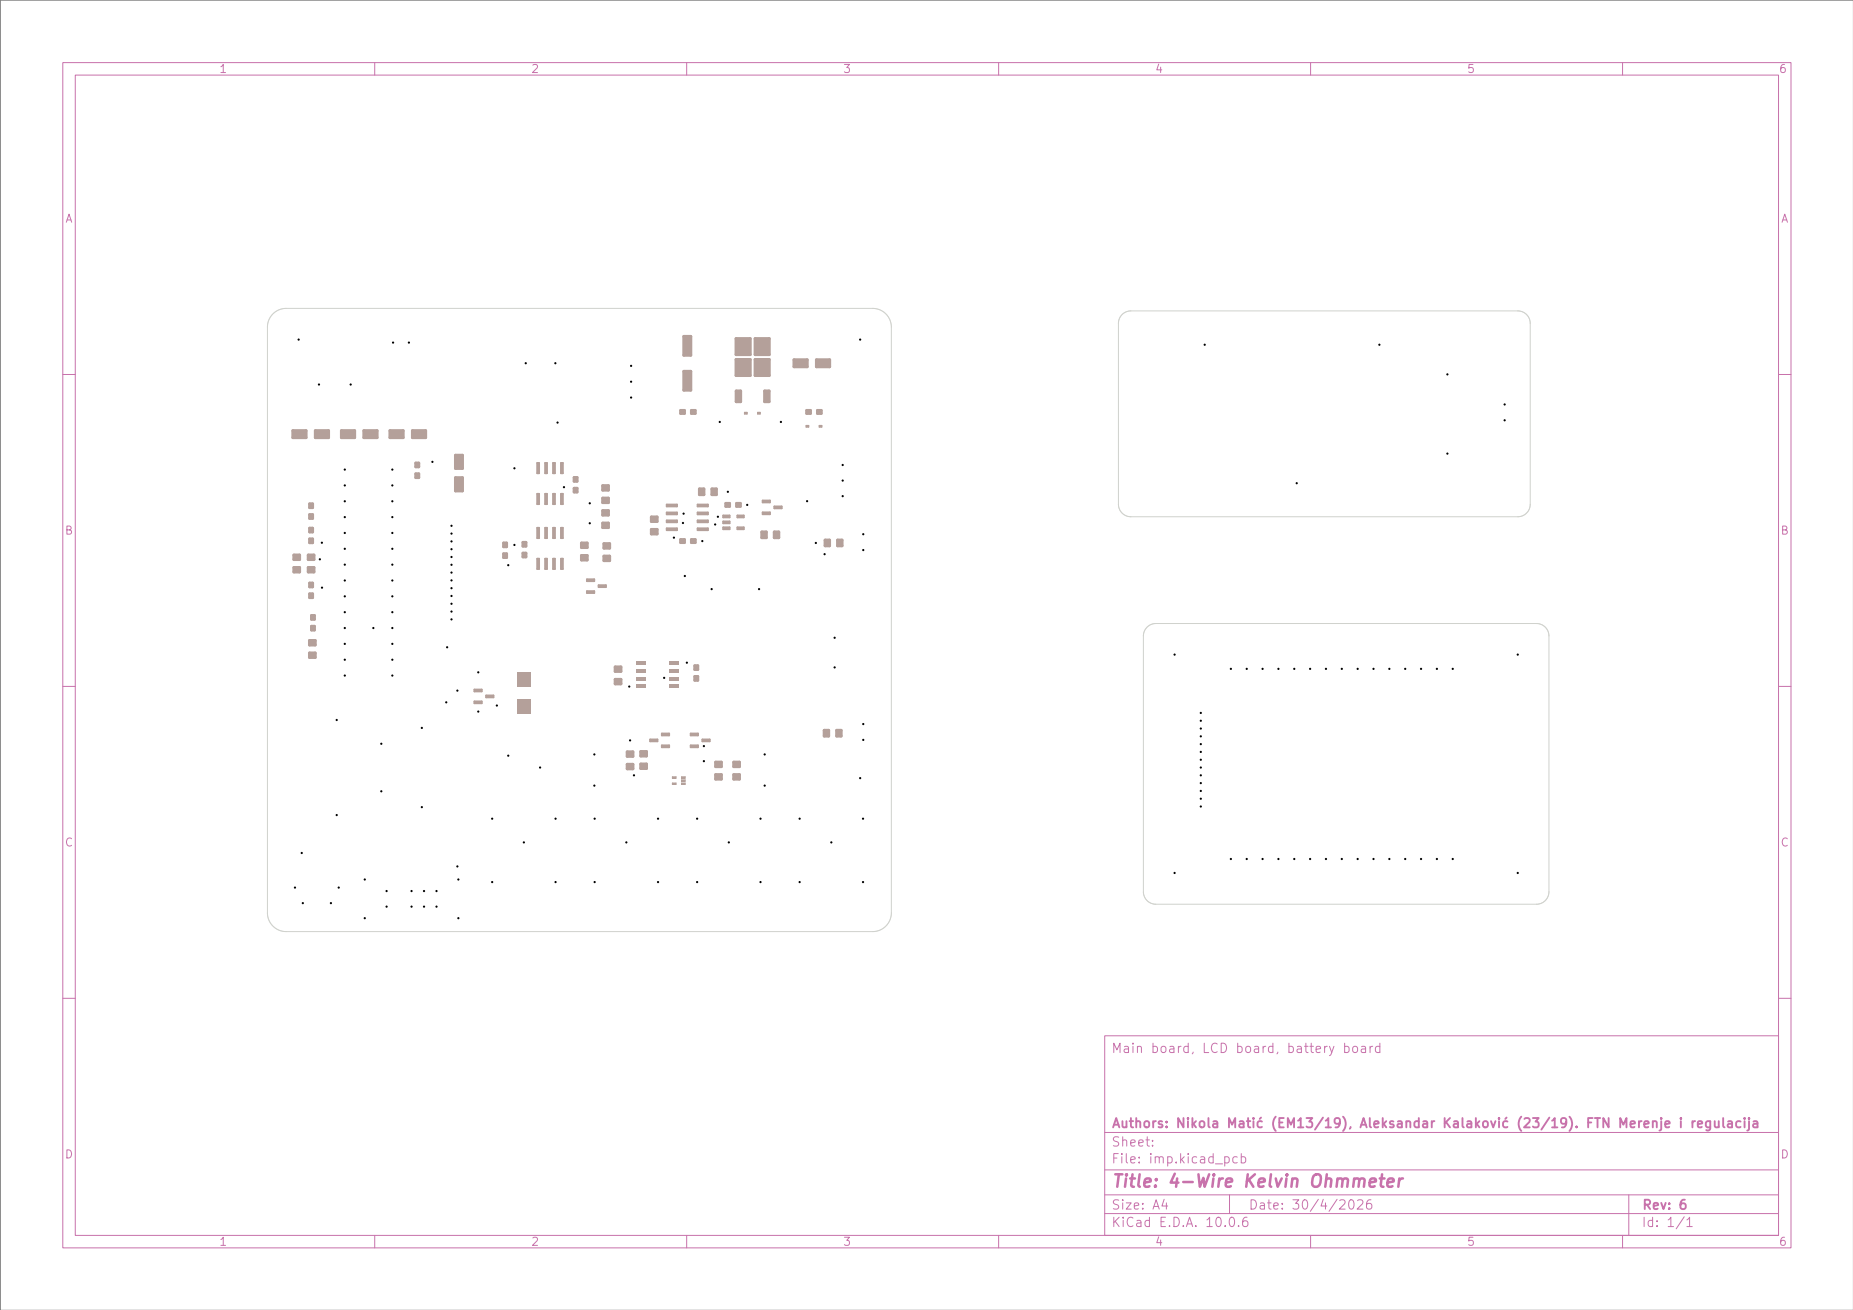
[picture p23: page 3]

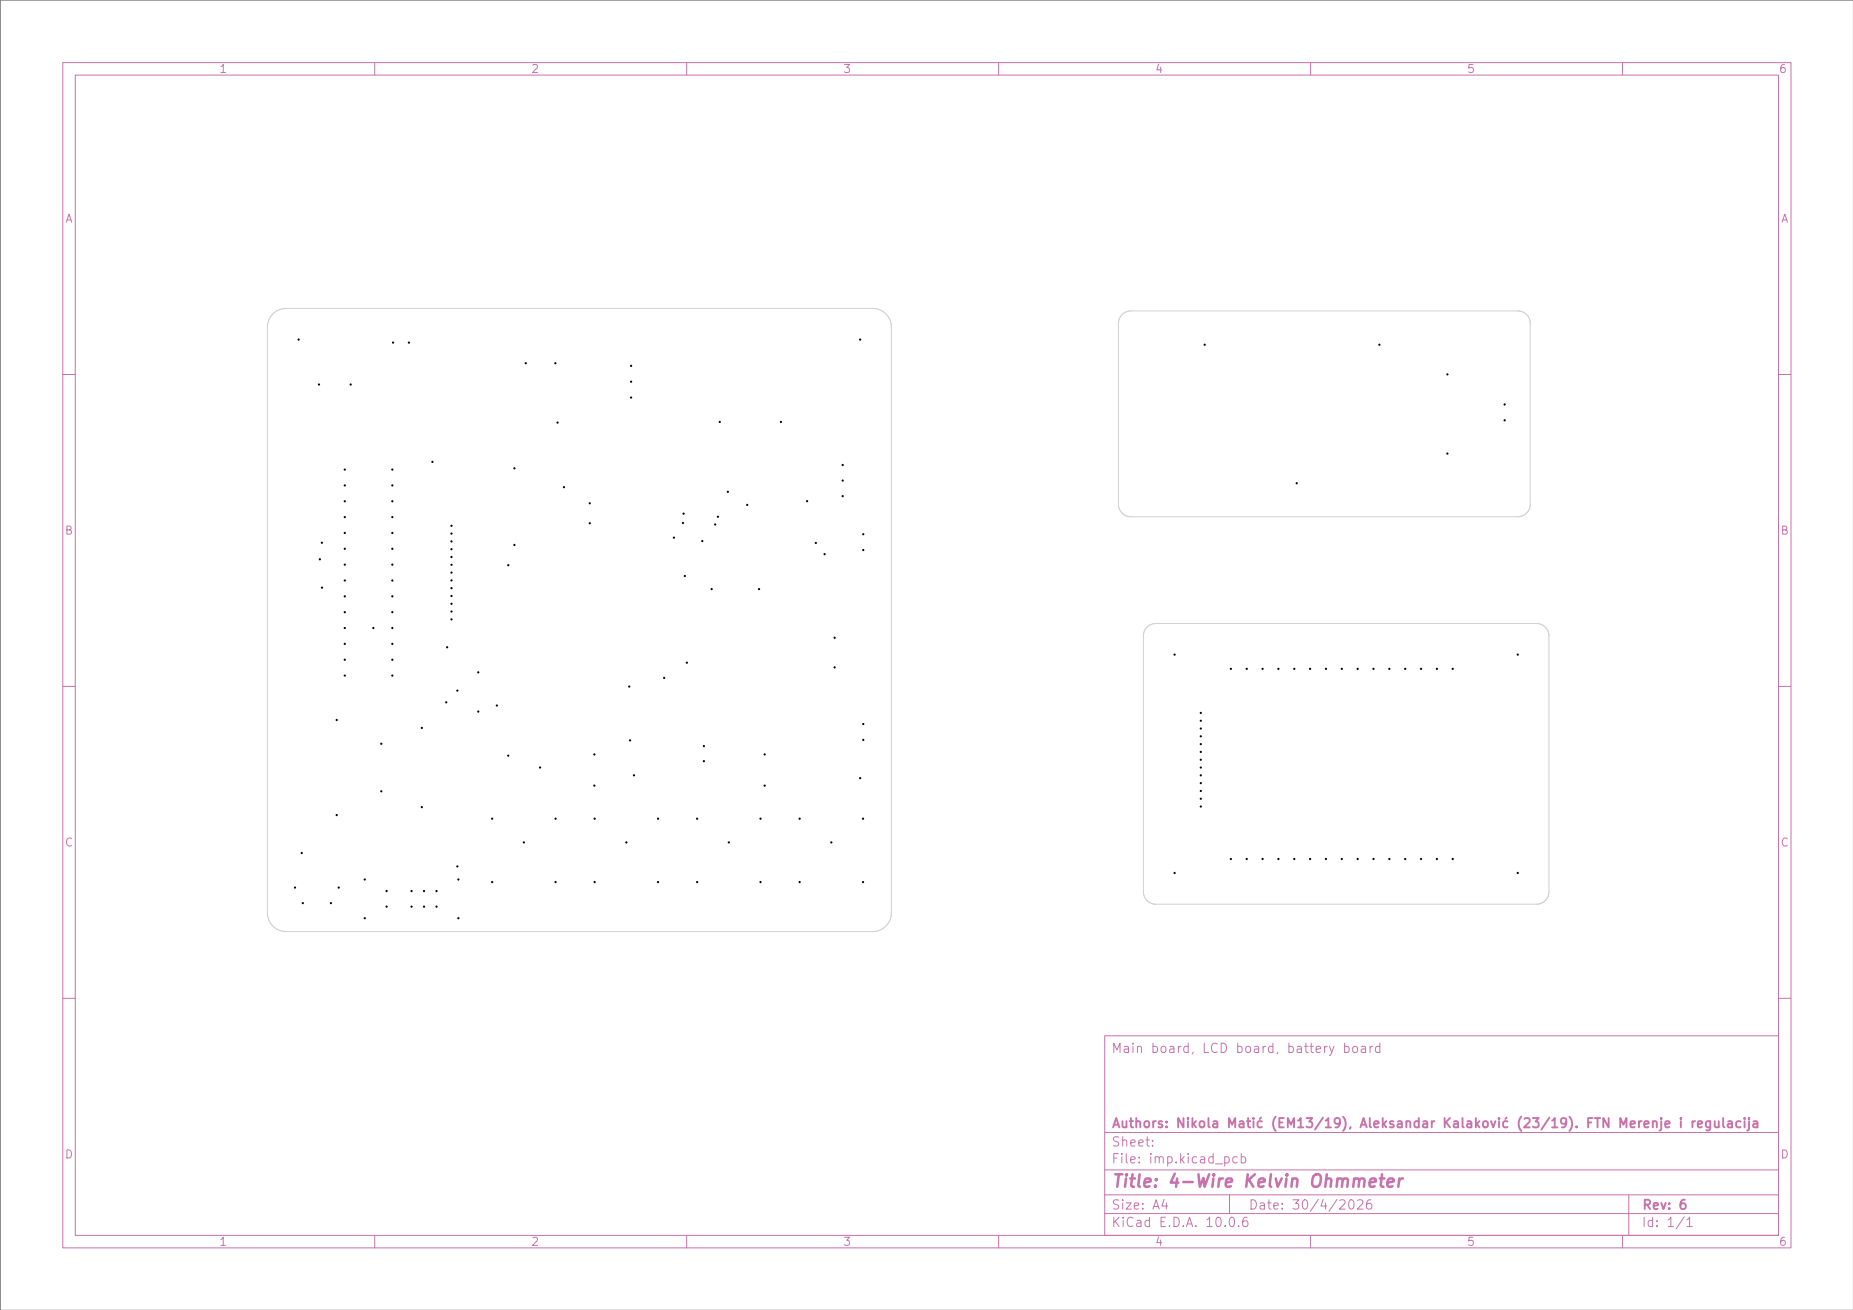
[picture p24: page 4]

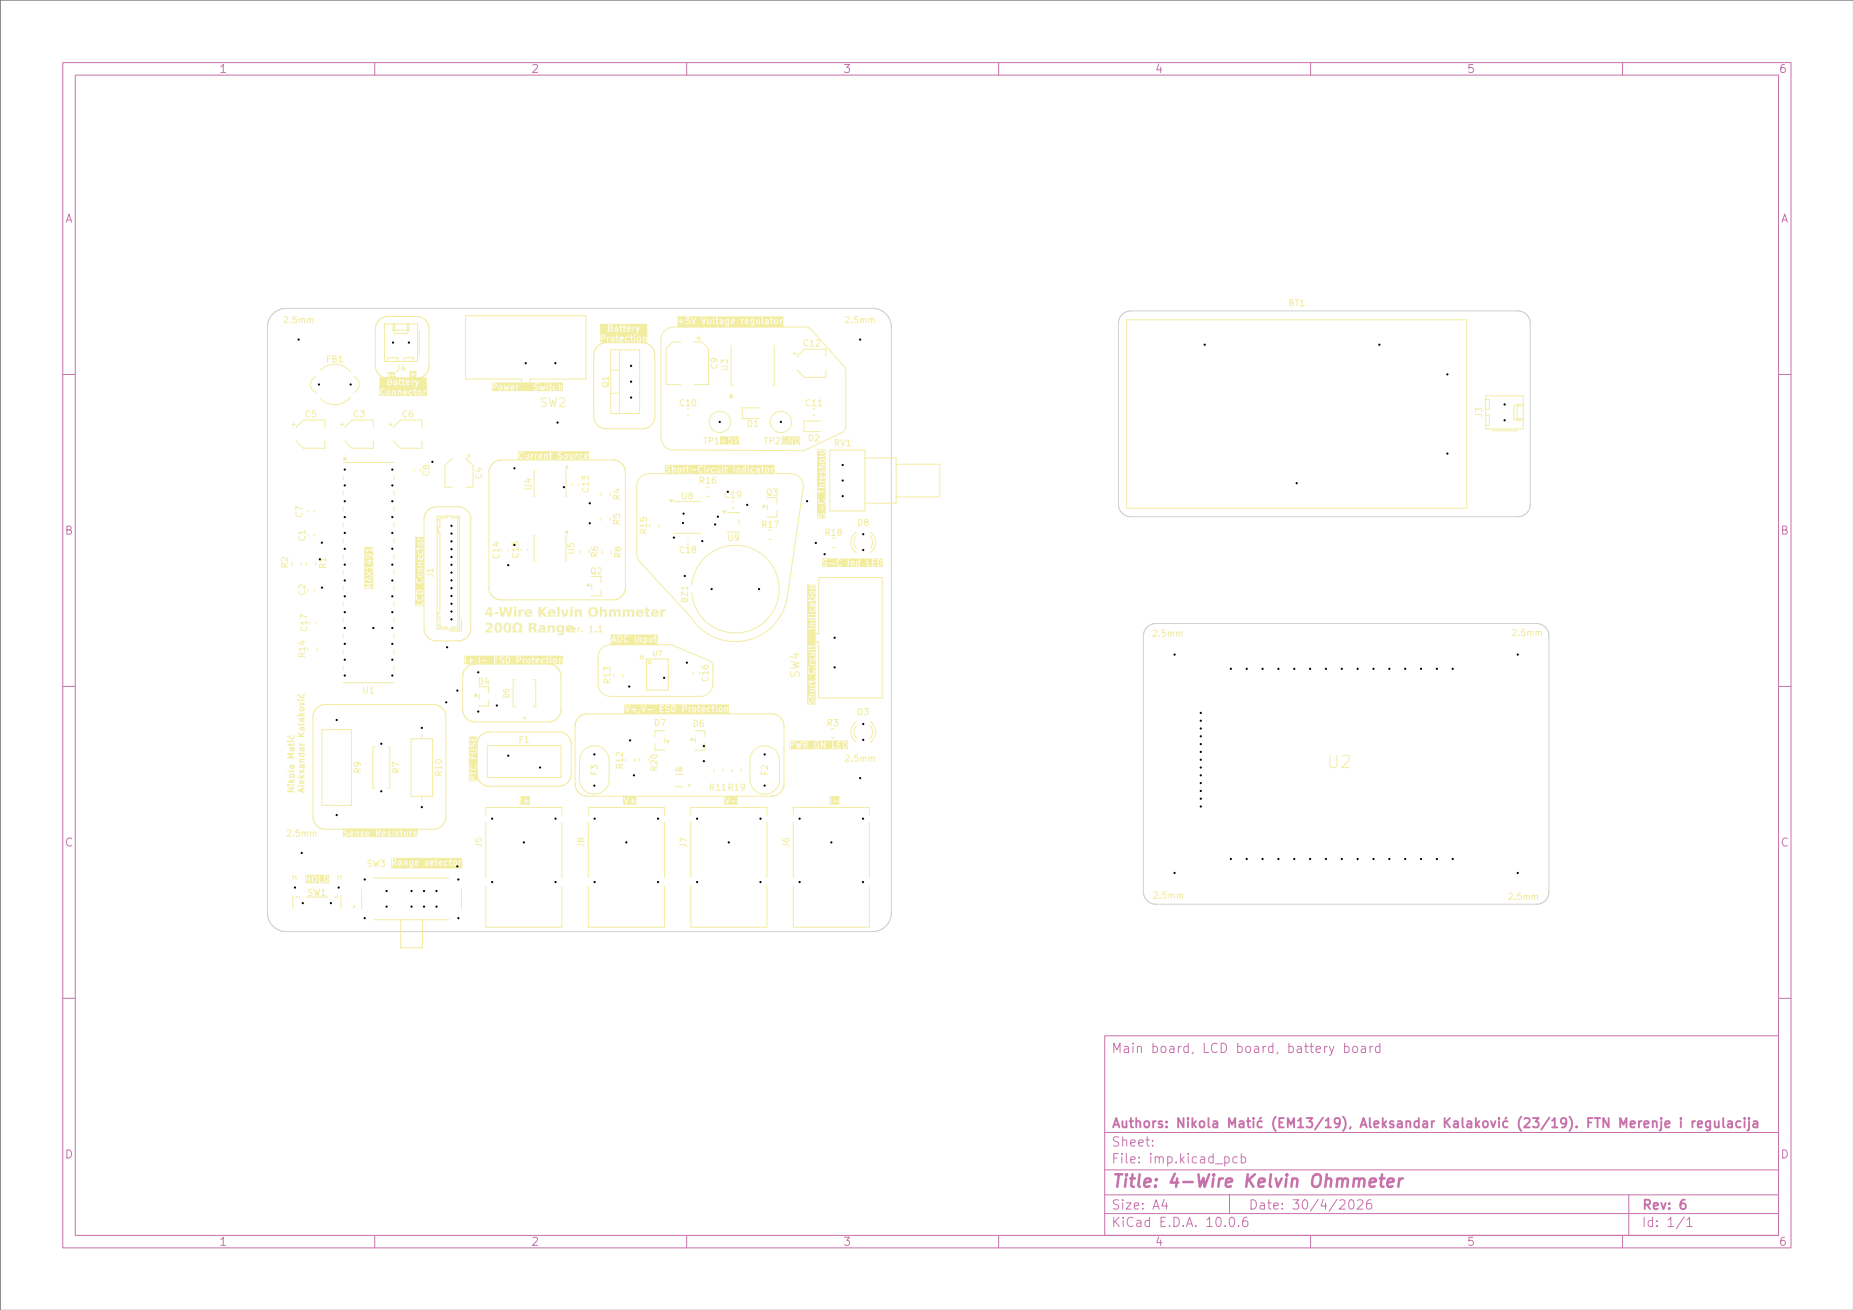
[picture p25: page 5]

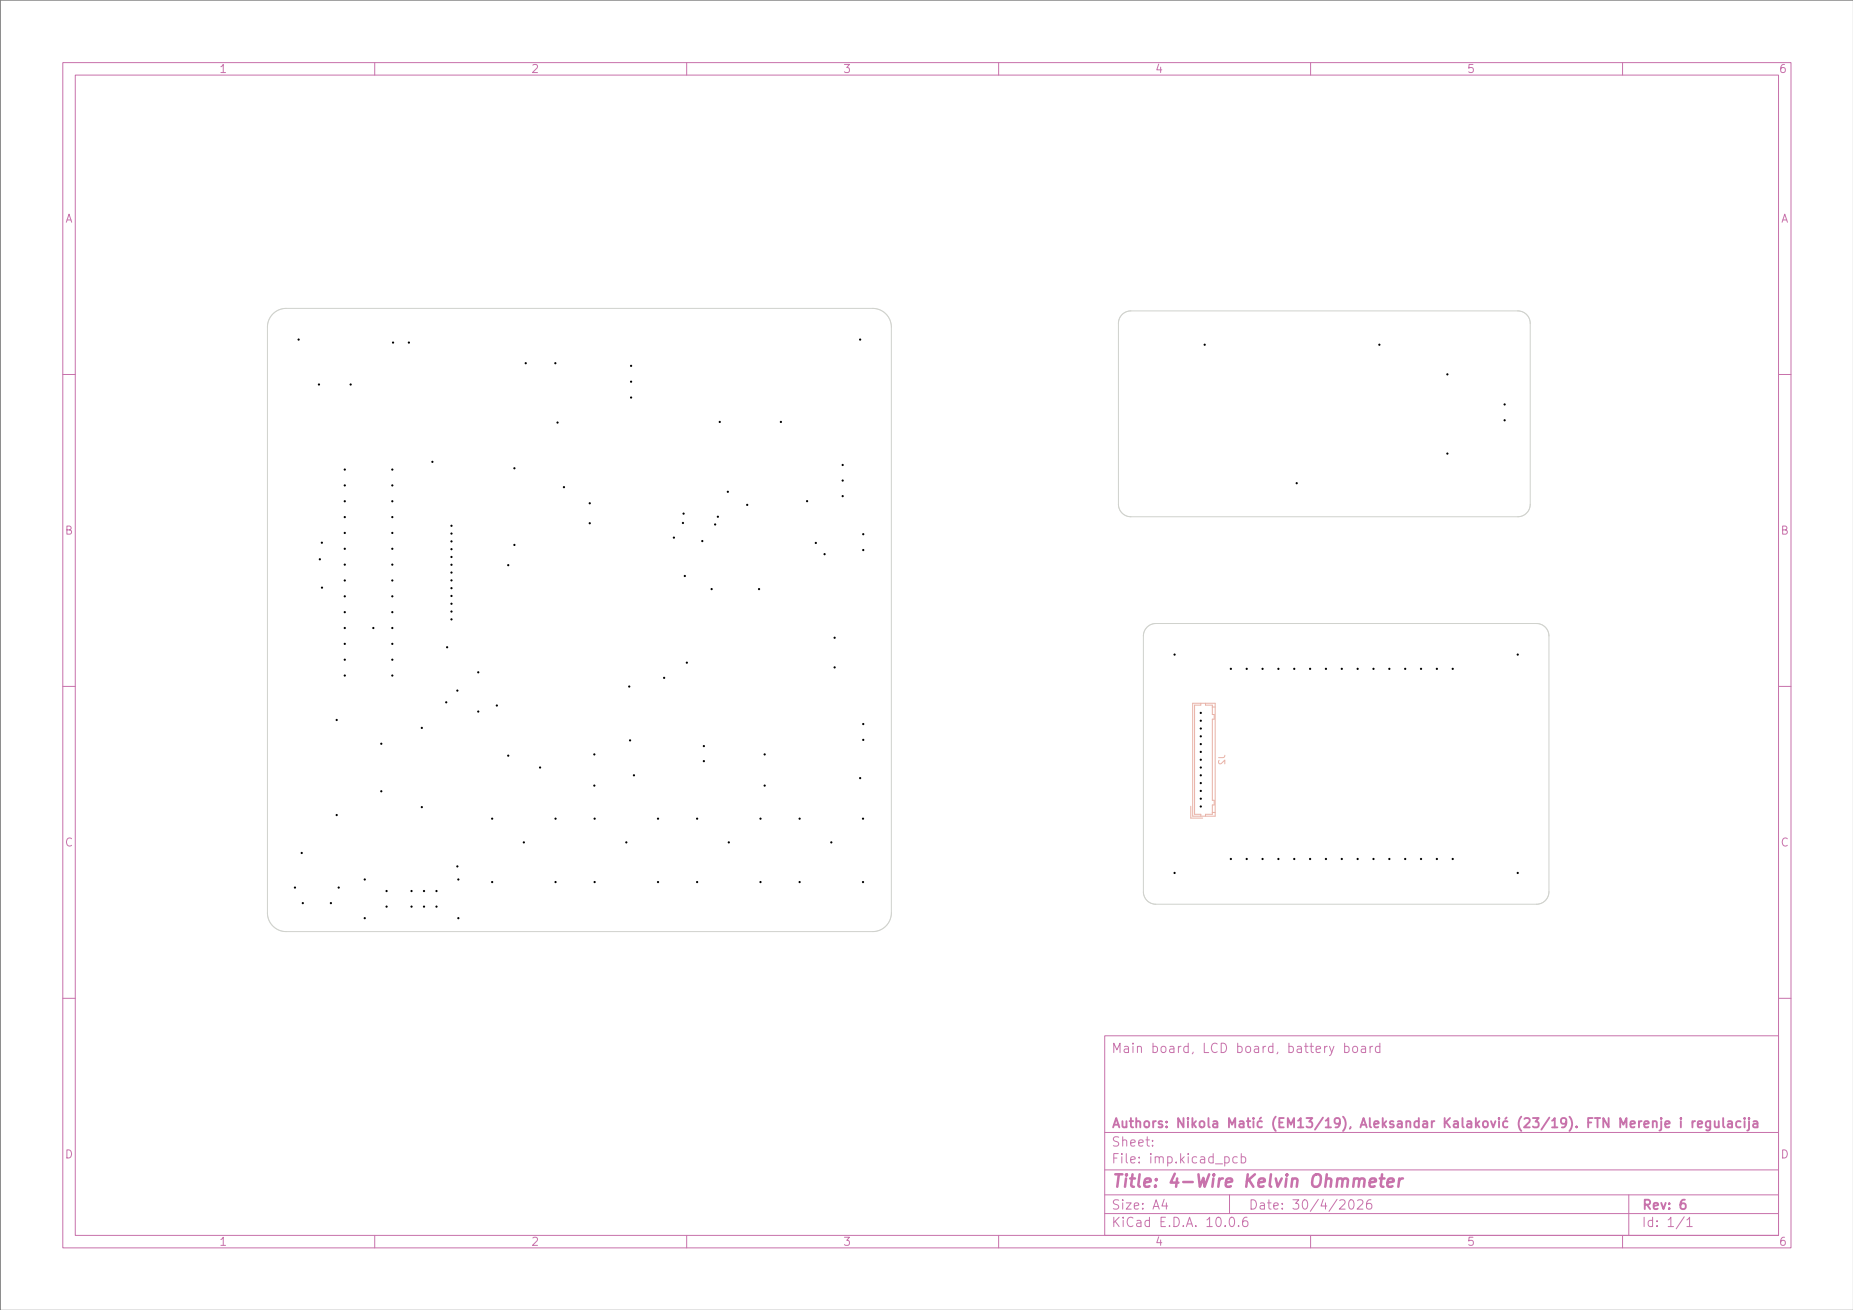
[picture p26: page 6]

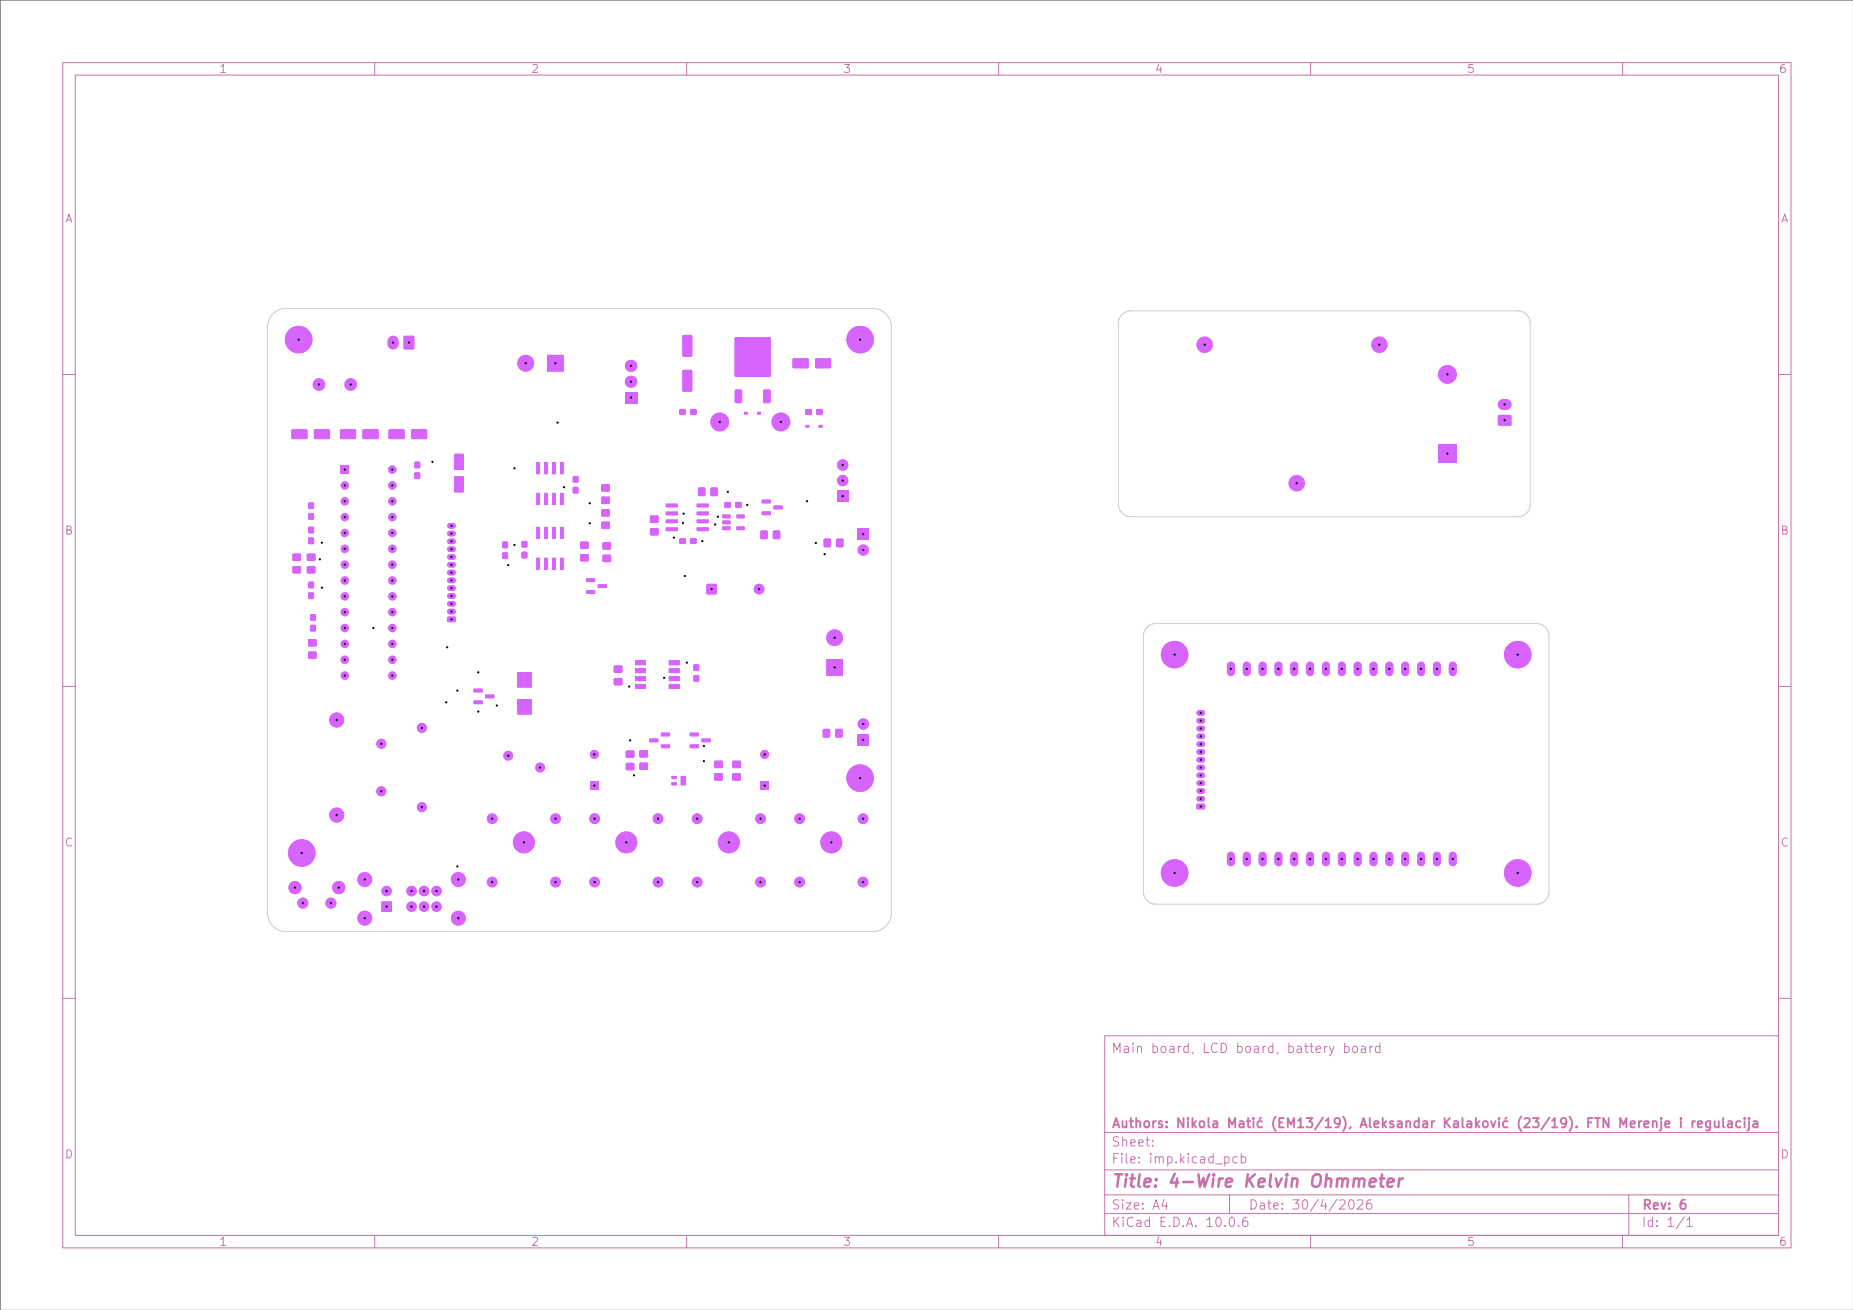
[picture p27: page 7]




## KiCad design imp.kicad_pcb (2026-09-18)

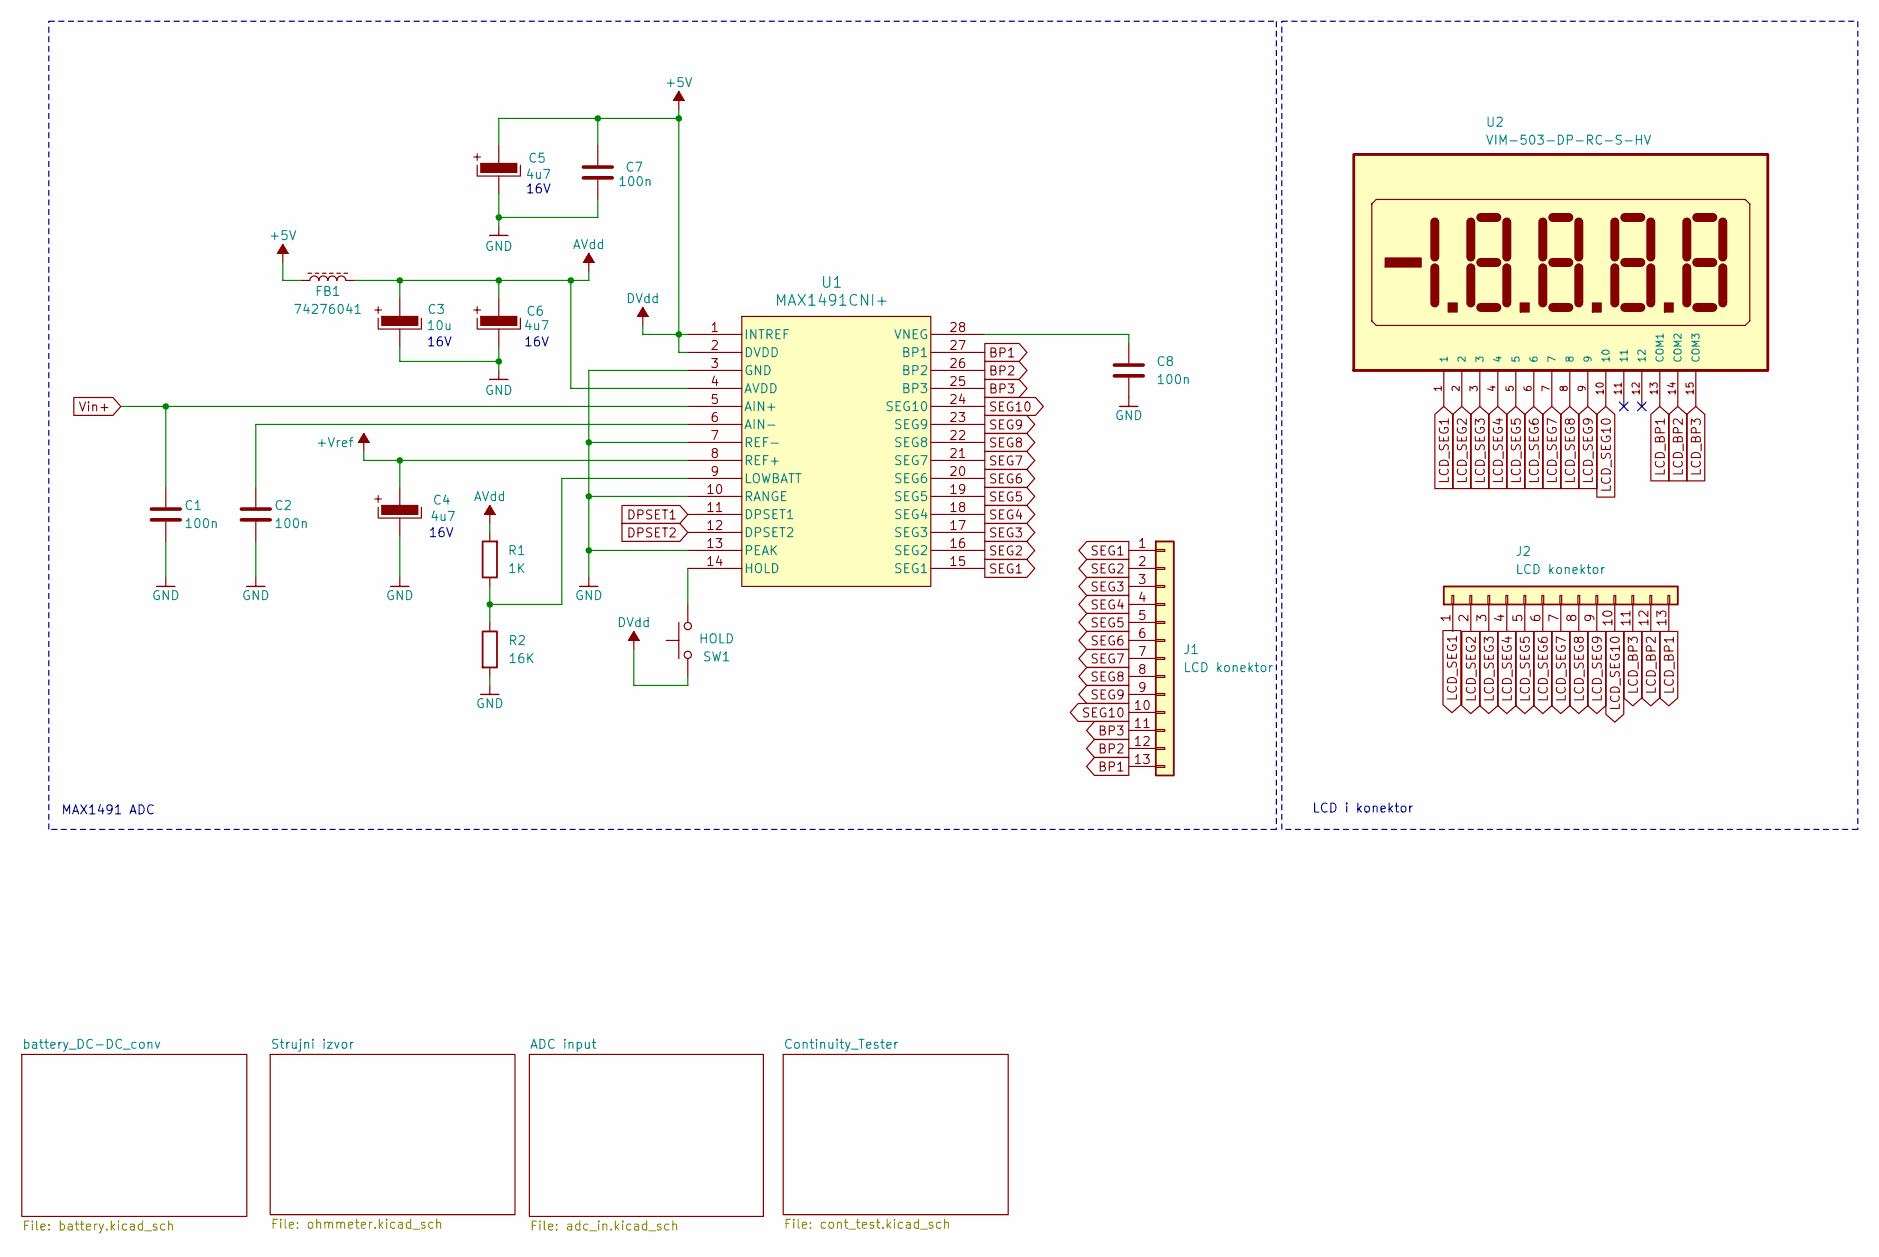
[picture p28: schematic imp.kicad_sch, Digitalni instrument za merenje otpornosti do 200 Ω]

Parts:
C1, C2, C7, C8: 100n; C_0603_1608Metric_Pad1.08x0.95mm_HandSolder
C3: 10u; CP_Elec_4x5.4
C4, C5, C6: 4u7; CP_Elec_4x5.4
FB1: 74276041; LairdTech_28C0236-0JW-10
J1, J2: LCD konektor; Hirose_DF13-13P-1.25DSA_1x13_P1.25mm_Vertical
R1: 1K; R_0805_2012Metric_Pad1.20x1.40mm_HandSolder
R2: 16K; R_0805_2012Metric_Pad1.20x1.40mm_HandSolder
SW1: HOLD; SW_Tactile_SPST_Angled_PTS645Vx83-2LFS
U1: MAX1491CNI+; 21-0043D_28_MXM
U2: VIM-503-DP-RC-S-HV; LCD_VIM-503-DP-RC-S-HV; DigiKey_Part_Number 153-1054-ND

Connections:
+5V: C5.1, C7.1, FB1.1, SW1.1, U1.1 (INTREF), U1.2 (DVDD); also elsewhere on the board
+Vref: C4.1, U1.8 (REF+); also elsewhere on the board
AVdd: C3.1, C6.1, FB1.2, R1.2, U1.4 (AVDD)
BP1: J1.13, U1.27 (BP1)
BP2: J1.12, U1.26 (BP2)
BP3: J1.11, U1.25 (BP3)
DPSET1: U1.11 (DPSET1); also elsewhere on the board
DPSET2: U1.12 (DPSET2); also elsewhere on the board
GND: C1.2, C2.2, C3.2, C4.2, C5.2, C6.2, C7.2, C8.2, R2.2, U1.3 (GND), U1.7 (REF-), U1.10 (RANGE), U1.13 (PEAK); also elsewhere on the board
LCD_BP1: J2.13, U2.13 (COM1)
LCD_BP2: J2.12, U2.14 (COM2)
LCD_BP3: J2.11, U2.15 (COM3)
LCD_SEG1: J2.1, U2.1
LCD_SEG2: J2.2, U2.2
LCD_SEG3: J2.3, U2.3
LCD_SEG4: J2.4, U2.4
LCD_SEG5: J2.5, U2.5
LCD_SEG6: J2.6, U2.6
LCD_SEG7: J2.7, U2.7
LCD_SEG8: J2.8, U2.8
LCD_SEG9: J2.9, U2.9
LCD_SEG10: J2.10, U2.10
unnamed: C2.1, U1.6 (AIN-)
unnamed: SW1.2, U1.14 (HOLD)
unnamed: R1.1, R2.1, U1.9 (LOWBATT)
unnamed: C8.1, U1.28 (VNEG)
SEG1: J1.1, U1.15 (SEG1)
SEG2: J1.2, U1.16 (SEG2)
SEG3: J1.3, U1.17 (SEG3)
SEG4: J1.4, U1.18 (SEG4)
SEG5: J1.5, U1.19 (SEG5)
SEG6: J1.6, U1.20 (SEG6)
SEG7: J1.7, U1.21 (SEG7)
SEG8: J1.8, U1.22 (SEG8)
SEG9: J1.9, U1.23 (SEG9)
SEG10: J1.10, U1.24 (SEG10)
Vin+: C1.1, U1.5 (AIN+); also elsewhere on the board

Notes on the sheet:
LCD i konektor
16V
MAX1491 ADC

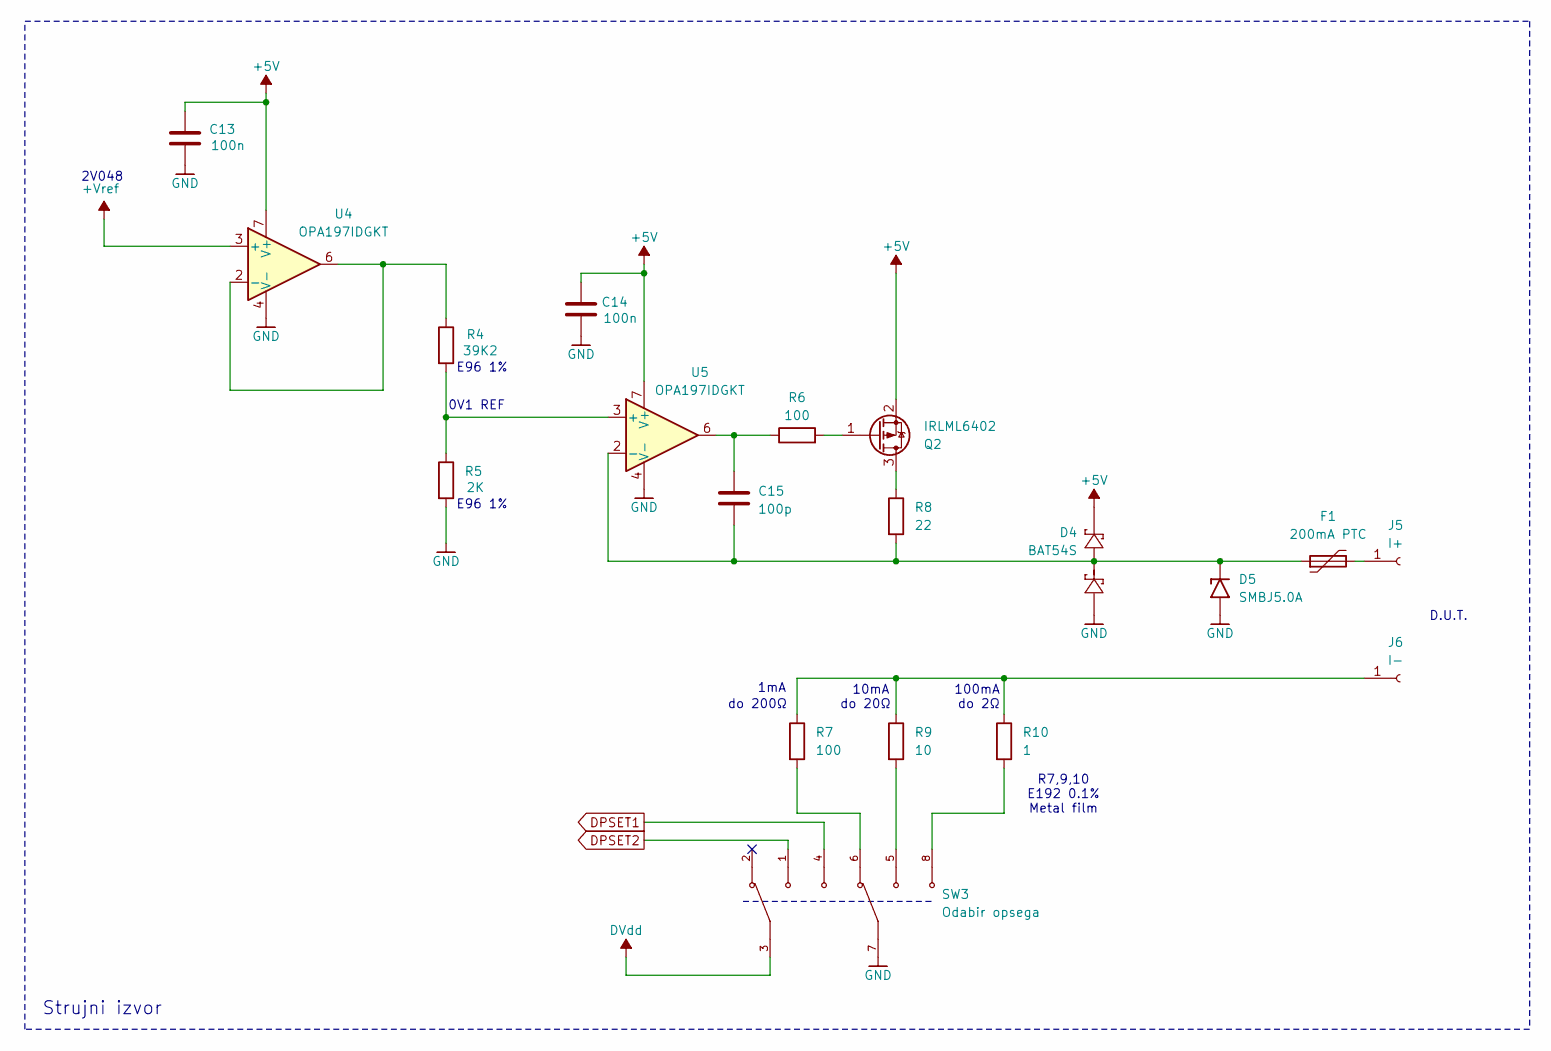
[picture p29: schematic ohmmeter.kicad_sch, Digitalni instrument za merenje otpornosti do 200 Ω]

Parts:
C13, C14: 100n; C_0603_1608Metric_Pad1.08x0.95mm_HandSolder
C15: 100p; C_0603_1608Metric_Pad1.08x0.95mm_HandSolder
D4: BAT54S; SOT-23
D5: SMBJ5.0A; DIOM4336X265N; PARTREV F2102
F1: 200mA PTC; Fuse_BelFuse_0ZRE0075FF_L11.5mm_W4.8mm
J5: I+; Banana_Cliff_FCR7350R_S16N-PC_Horizontal
J6: I-; Banana_Cliff_FCR7350B_S16N-PC_Horizontal
Q2: IRLML6402; SOT-23
R4: 39K2; R_0805_2012Metric_Pad1.20x1.40mm_HandSolder
R5: 2K; R_0805_2012Metric_Pad1.20x1.40mm_HandSolder
R6: 100; R_0805_2012Metric_Pad1.20x1.40mm_HandSolder
R7: 100; R_Axial_DIN0207_L6.3mm_D2.5mm_P7.62mm_Horizontal; Part No. PTF56100R00BYEB
R8: 22; R_0805_2012Metric_Pad1.20x1.40mm_HandSolder
R9: 10; R_Axial_DIN0414_L11.9mm_D4.5mm_P15.24mm_Horizontal; Part No. UPF50B10RV
R10: 1; R_Axial_DIN0309_L9.0mm_D3.2mm_P12.70mm_Horizontal; Part No. RS1/21R000BB12
SW3: Odabir opsega; SW_MHS233RA04; PARTREV C
U4, U5: OPA197IDGKT; SOIC-8_3.9x4.9mm_P1.27mm

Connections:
+5V: C13.1, C14.1, D4.2 (K), Q2.2 (S), SW3.3, U4.7 (V+), U5.7 (V+); also elsewhere on the board
+Vref: U4.3 (+); also elsewhere on the board
DPSET1: SW3.4; also elsewhere on the board
DPSET2: SW3.1; also elsewhere on the board
GND: C13.2, C14.2, D4.1 (A), D5.A, R5.2, SW3.7, U4.4 (V-), U5.4 (V-); also elsewhere on the board
unnamed: C15.1, R6.1, U5.6
unnamed: C15.2, D4.3 (COM), D5.K, F1.1, R8.2, U5.2 (-)
unnamed: F1.2, J5.1 (Pin_1_1)
unnamed: J6.1 (Pin_1_1), R7.1, R9.1, R10.1
unnamed: Q2.3 (D), R8.1
unnamed: Q2.1 (G), R6.2
unnamed: R7.2, SW3.6
unnamed: R9.2, SW3.5
unnamed: R10.2, SW3.8
unnamed: R4.1, U4.2 (-), U4.6
unnamed: R4.2, R5.1, U5.3 (+)

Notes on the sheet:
1mA
D.U.T.
E96 1%
do 20Ω
Strujni izvor
2V048
10mA
0V1 REF
R7,9,10 E192 0.1% Metal film
do 200Ω
100mA
do 2Ω

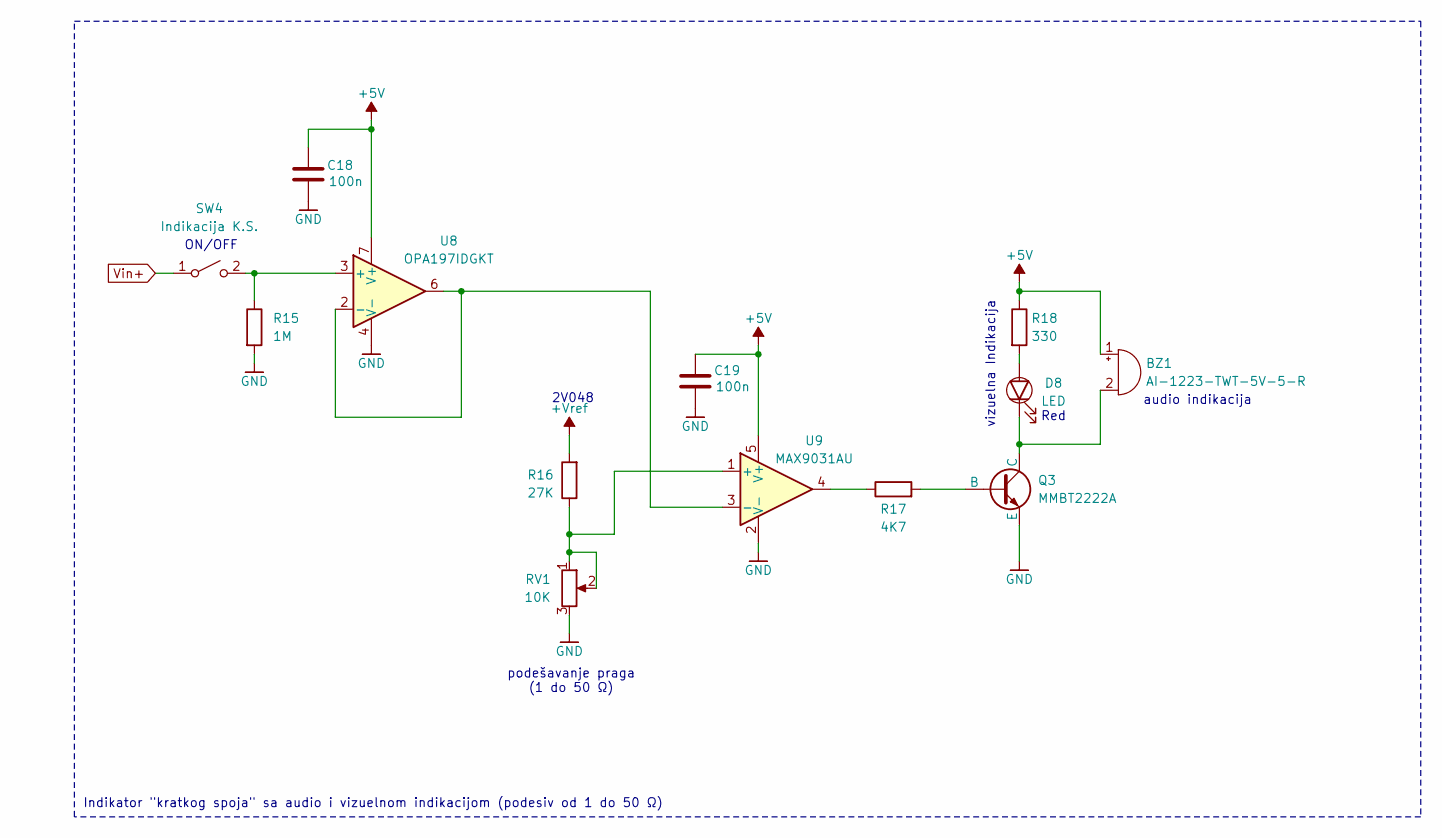
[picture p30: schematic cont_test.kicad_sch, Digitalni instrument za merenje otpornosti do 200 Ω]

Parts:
BZ1: AI-1223-TWT-5V-5-R; Indicator_PUI_AI-1440-TWT-24V-2-R
C18, C19: 100n; C_0603_1608Metric_Pad1.08x0.95mm_HandSolder
D8: LED; LED_D3.0mm
Q3: MMBT2222A; SOT-23
R15: 1M; R_0805_2012Metric_Pad1.20x1.40mm_HandSolder
R16: 27K; R_0805_2012Metric_Pad1.20x1.40mm_HandSolder
R17: 4K7; R_0805_2012Metric_Pad1.20x1.40mm_HandSolder
R18: 330; R_0805_2012Metric_Pad1.20x1.40mm_HandSolder
RV1: 10K; Potentiometer_Alps_RK09Y11_Single_Horizontal
SW4: Indikacija K.S.; SW_L101011ML04Q
U8: OPA197IDGKT; SOIC-8_3.9x4.9mm_P1.27mm
U9: MAX9031AU; SOT-23-5

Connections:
+5V: BZ1.1 (+), C18.1, C19.1, R18.1, U8.7 (V+), U9.5 (V+); also elsewhere on the board
+Vref: R16.2; also elsewhere on the board
GND: C18.2, C19.2, Q3.3 (E), R15.2, RV1.3, U8.4 (V-), U9.2 (V-); also elsewhere on the board
unnamed: BZ1.2 (-), D8.1 (K), Q3.1 (C)
unnamed: D8.2 (A), R18.2
unnamed: Q3.2 (B), R17.2
unnamed: R17.1, U9.4
unnamed: R15.1, SW4.2 (B), U8.3 (+)
unnamed: U8.2 (-), U8.6, U9.3 (-)
unnamed: R16.1, RV1.1, RV1.2, U9.1 (+)
Vin+: SW4.1 (A); also elsewhere on the board

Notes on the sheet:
ON/OFF
podešavanje praga (1 do 50 Ω)
Red
2V048
vizuelna Indikacija
Indikator "kratkog spoja" sa audio i vizuelnom indikacijom (podesiv od 1 do 50 Ω)
audio indikacija

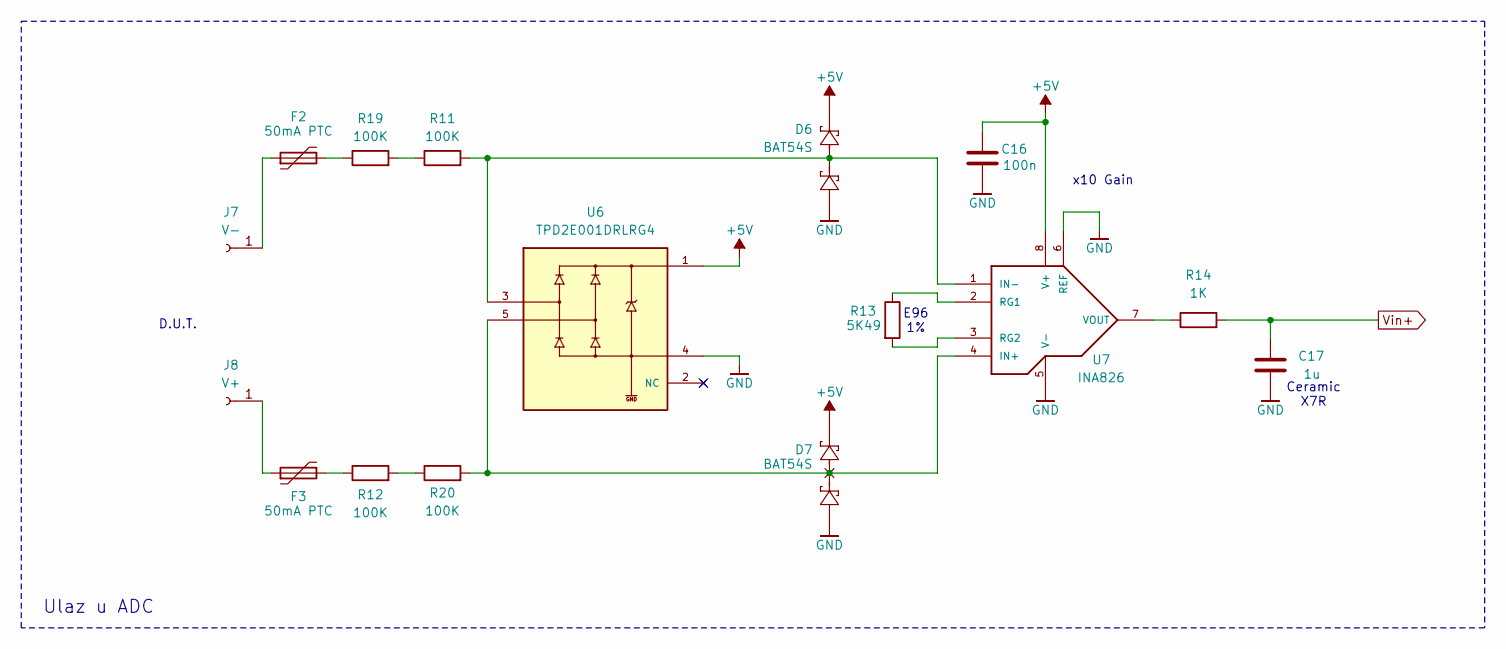
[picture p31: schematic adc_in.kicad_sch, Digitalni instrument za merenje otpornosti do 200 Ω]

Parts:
C16: 100n; C_0603_1608Metric_Pad1.08x0.95mm_HandSolder
C17: 1u; C_0603_1608Metric_Pad1.08x0.95mm_HandSolder
D6, D7: BAT54S; SOT-23
F2, F3: 50mA PTC; FUSE_CMF-RL50A-0_BRN
J7: V-; Banana_Cliff_FCR7350G_S16N-PC_Horizontal
J8: V+; Banana_Cliff_FCR7350G_S16N-PC_Horizontal
R11, R12, R19, R20: 100K; R_0805_2012Metric_Pad1.20x1.40mm_HandSolder
R13: 5K49; R_0805_2012Metric_Pad1.20x1.40mm_HandSolder
R14: 1K; R_0805_2012Metric_Pad1.20x1.40mm_HandSolder
U6: TPD2E001DRLRG4; SOTFL50P160X60-5N; PARTREV I
U7: INA826; SO-8

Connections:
+5V: C16.1, D6.2 (K), D7.2 (K), U6.1, U7.8 (V+); also elsewhere on the board
GND: C16.2, C17.2, D6.1 (A), D7.1 (A), U6.4, U7.5 (V-), U7.6 (REF); also elsewhere on the board
unnamed: D6.3 (COM), R11.2, U6.3, U7.1 (IN-)
unnamed: D7.3 (COM), R20.2, U6.5, U7.4 (IN+)
unnamed: F2.2, R19.1
unnamed: F3.2, R12.1
unnamed: F2.1, J7.1 (Pin_1_1)
unnamed: F3.1, J8.1 (Pin_1_1)
unnamed: R11.1, R19.2
unnamed: R12.2, R20.1
unnamed: R13.1, U7.2 (RG1)
unnamed: R13.2, U7.3 (RG2)
unnamed: R14.1, U7.7 (VOUT)
Vin+: C17.1, R14.2; also elsewhere on the board

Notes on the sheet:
x10 Gain
D.U.T.
E96 1%
Ulaz u ADC
Ceramic X7R

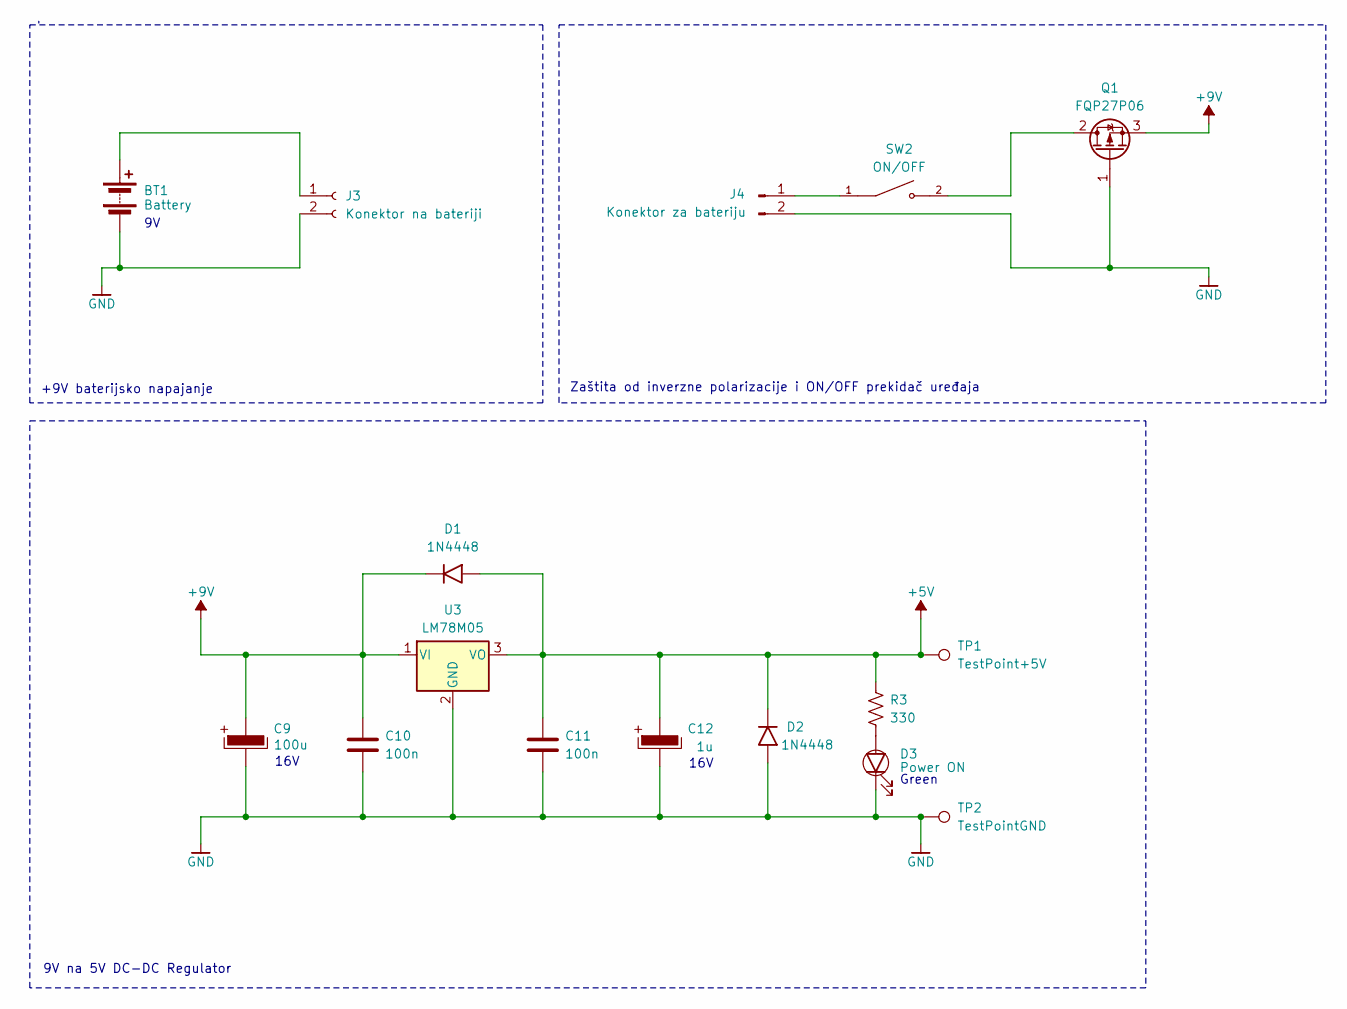
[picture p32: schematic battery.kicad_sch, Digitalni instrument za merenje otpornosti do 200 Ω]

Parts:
BT1: Battery; BatteryHolder_Eagle_12BH611-GR
C9: 100u; CP_Elec_6.3x5.9
C10, C11: 100n; C_0603_1608Metric_Pad1.08x0.95mm_HandSolder
C12: 1u; CP_Elec_4x4.5
D1, D2: 1N4448; D_SOD-323
D3: Power ON; LED_D3.0mm
J3: Konektor na bateriji; Molex_KK-254_AE-6410-02A_1x02_P2.54mm_Vertical
J4: Konektor za bateriju; Molex_KK-254_AE-6410-02A_1x02_P2.54mm_Vertical
Q1: FQP27P06; TO-220-3_Vertical
R3: 330; R_0805_2012Metric_Pad1.20x1.40mm_HandSolder
SW2: ON/OFF; SW_L101011ML04Q; PARTREV 19 Mar 2019
TP1: TestPoint+5V; TestPoint_Loop_D2.54mm_Drill1.5mm_Beaded
TP2: TestPointGND; TestPoint_Loop_D2.54mm_Drill1.5mm_Beaded
U3: LM78M05; TO-252-2

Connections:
+5V: C11.1, C12.1, D1.2 (A), D2.1 (K), R3.1, TP1.1 (1_1), U3.3 (VO); also elsewhere on the board
+9V: C9.1, C10.1, D1.1 (K), Q1.3 (S), U3.1 (VI)
GND: BT1.2 (-), C9.2, C10.2, C11.2, C12.2, D2.2 (A), D3.1 (K), J3.2, J4.2, Q1.1 (G), TP2.1 (1_1), U3.2 (GND); also elsewhere on the board
unnamed: BT1.1 (+), J3.1
unnamed: D3.2 (A), R3.2
unnamed: J4.1, SW2.1
unnamed: Q1.2 (D), SW2.2

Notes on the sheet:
16V
9V na 5V DC-DC Regulator
+9V baterijsko napajanje
Green
Zaštita od inverzne polarizacije i ON/OFF prekidač uređaja

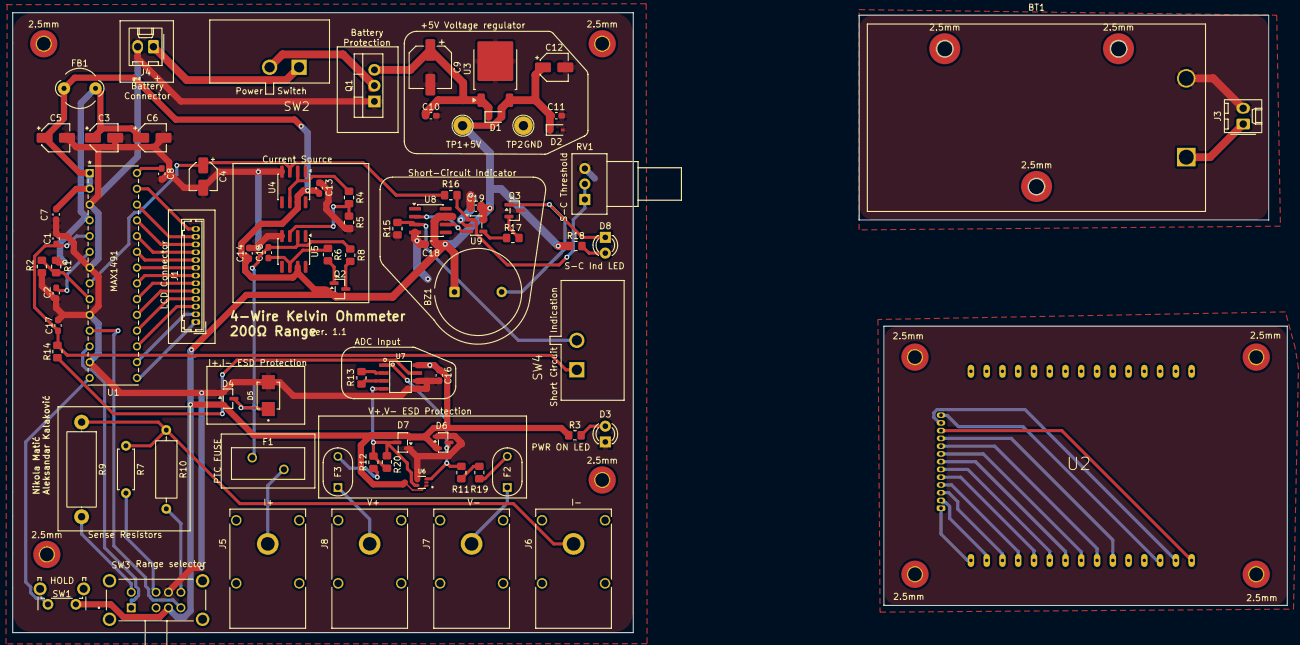
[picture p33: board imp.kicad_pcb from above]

Board: 2 copper layers, 100.0 x 99.9 mm, 91 parts (1 on the bottom side), 71 nets.

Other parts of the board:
2.5mm, 2.5mm#2, 2.5mm#4: MountingHole_2.5mm_Pad_TopBottom
2.5mm#3, 2.5mm#5, 2.5mm#6, 2.5mm#7, 2.5mm#8, 2.5mm#9, 2.5mm#10, 2.5mm#11: MountingHole_2.2mm_M2_Pad_TopBottom
